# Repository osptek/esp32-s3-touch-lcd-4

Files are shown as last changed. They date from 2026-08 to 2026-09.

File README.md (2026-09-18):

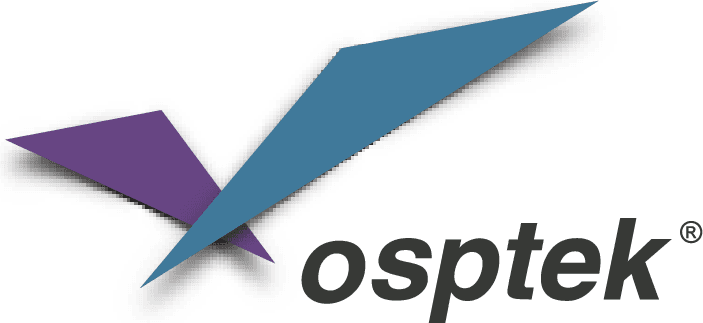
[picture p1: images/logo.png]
OSPTEK


<h1 align="center">OSPTEK ESP32-S3-Touch-LCD-4 系列</h1>

<p align="center"><b>4 寸触摸面板 · 多版本索引 · ESP32-S3</b></p>

<p align="center"><a href="./README_EN.md">English</a> | 简体中文</p>

<p align="center">
  
  
  
  
</p>

## 目录

- [说明](#说明)
- [版本一览](#版本一览)
- [ESP32-S3-Touch-LCD-4](#esp32-s3-touch-lcd-4)
- [ESP32-S3-Touch-4-Classic](#esp32-s3-touch-4-classic)
- [ESP32-S3-Touch-4-Pro](#esp32-s3-touch-4-pro)
- [ESP32-S3-Touch-4-220V](#esp32-s3-touch-4-220v)
- [外壳 CAD](#外壳-cad)
- [购买链接](#购买链接)
- [技术支持](#技术支持)

---

## 说明

本仓库收录 **ESP32-S3-Touch-LCD-4 系列** 4 寸触摸屏面板成品资料。

**根目录 README 为导航页**。下表可快速浏览各版本；点击「完整资料」进入 `versions/` 下对应**型号文件夹**（产品页、规格书、示例、固件均在该目录内）。

仓库名：`esp32-s3-touch-lcd-4`

---

## 版本一览

| 版本 | 宣传图 | 简介 | 完整资料 |
| ---- | --- | ---- | --- |
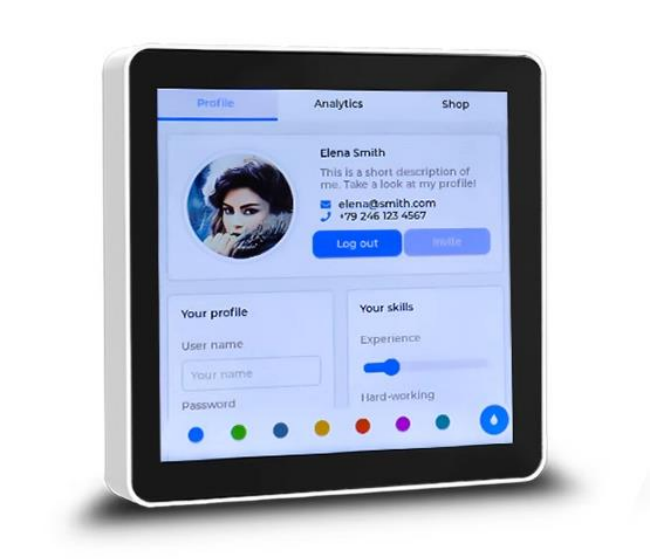
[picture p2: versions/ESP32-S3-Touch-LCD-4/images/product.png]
ESP32-S3-Touch-LCD-4
| ESP32-S3-Touch-LCD-4 |  | [简介](#esp32-s3-touch-lcd-4) | [完整资料](./versions/ESP32-S3-Touch-LCD-4/) |
| ESP32-S3-Touch-4-Classic | ESP32-S3-Touch-4-Classic | [简介](#esp32-s3-touch-4-classic) | [完整资料](./versions/ESP32-S3-Touch-4-Classic/) |
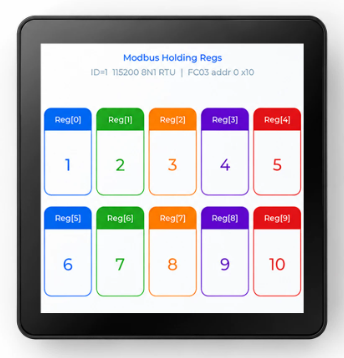
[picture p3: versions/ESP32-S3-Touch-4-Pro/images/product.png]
ESP32-S3-Touch-4-Pro
| ESP32-S3-Touch-4-Pro |  | [简介](#esp32-s3-touch-4-pro) | [完整资料](./versions/ESP32-S3-Touch-4-Pro/) |
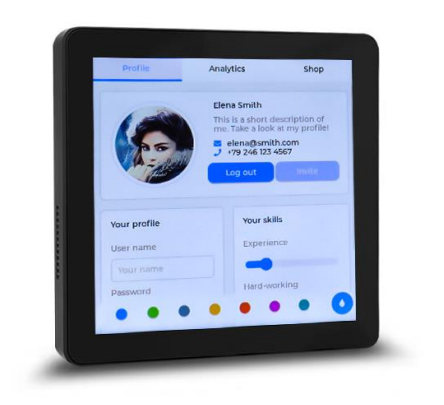
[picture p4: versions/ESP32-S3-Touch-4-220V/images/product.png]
ESP32-S3-Touch-4-220V
| ESP32-S3-Touch-4-220V |  | [简介](#esp32-s3-touch-4-220v) | [完整资料](./versions/ESP32-S3-Touch-4-220V/) |

---

## ESP32-S3-Touch-LCD-4

<p align="center">ESP32-S3-Touch-LCD-4</p>

**说明：** 旧版硬件（ESP32-TPCB4）；USB 5V / 12–24 VDC；一路 RS485。

完整产品页、规格书与示例：[versions/ESP32-S3-Touch-LCD-4/](./versions/ESP32-S3-Touch-LCD-4/)

---

## ESP32-S3-Touch-4-Classic

<p align="center">ESP32-S3-Touch-4-Classic</p>

**说明：** 新版基础板（原理图 `ESP32-S3-Touch基础板V1.0`）；示例工程 / 预编译固件已在本版验证。

完整产品页、规格书与示例：[versions/ESP32-S3-Touch-4-Classic/](./versions/ESP32-S3-Touch-4-Classic/)

---

## ESP32-S3-Touch-4-Pro

<p align="center">ESP32-S3-Touch-4-Pro</p>

**说明：** 新版 Pro；在 Classic 基础上增加板载音频（ES8311 + NS4150B）。

完整产品页、规格书与示例：[versions/ESP32-S3-Touch-4-Pro/](./versions/ESP32-S3-Touch-4-Pro/)

---

## ESP32-S3-Touch-4-220V

<p align="center">ESP32-S3-Touch-4-220V</p>

**说明：** 220V 交流供电版（AC 85–265 V）；一路 RS485。

完整产品页、规格书与示例：[versions/ESP32-S3-Touch-4-220V/](./versions/ESP32-S3-Touch-4-220V/)

---

## 外壳 CAD

本系列 **86 型外壳**（2 层 / 4 层）全型号通用。

**4 层外壳**

- [`0302(1).dwg`](./docs/86-enclosure-4-layer/0302(1).dwg)
- [`WSD4寸-2d-1116.dwg`](./docs/86-enclosure-4-layer/WSD4%E5%AF%B8-2d-1116.dwg)

**2 层外壳**

- [`3.95-01 PCB.dwg`](./docs/86-enclosure-2-layer/3.95-01%20PCB.dwg)
- [`增加开口结构外壳20250102.dwg`](./docs/86-enclosure-2-layer/%E5%A2%9E%E5%8A%A0%E5%BC%80%E5%8F%A3%E7%BB%93%E6%9E%84%E5%A4%96%E5%A3%B320250102.dwg)
- [`装配0718(1).DWG`](./docs/86-enclosure-2-layer/%E8%A3%85%E9%85%8D0718(1).DWG)

---

## 购买链接

<p align="center">
  
  &nbsp;&nbsp;
  
</p>

**国内（淘宝）**

- 店铺：[鱼鹰光电工厂店](https://shop110742373.taobao.com/)

**海外（AliExpress）**

- 店铺：[OSPTEK Official Store](https://www.aliexpress.com/store/1105701619)

---

## 技术支持

- 技术支持 / 产品咨询：<luyu@osptek.com>
- QQ 技术交流群：**985881096**
- 公司官网：<https://osptek.com/>
- 有任何问题，都可以在本仓库 Issues 中提问

---

<p align="center"><sub>© 2026 OSPTEK 鱼鹰光电 · 本仓库资料采用 CC BY 4.0 许可</sub></p>

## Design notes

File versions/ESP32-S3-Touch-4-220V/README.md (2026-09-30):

<p align="left">OSPTEK</p>

<h1 align="center">OSPTEK ESP32-S3-Touch-4-220V 触摸屏面板</h1>

<p align="center"><b>4 寸触摸 · 220V 供电 · RS485 · Wi-Fi / BLE</b></p>

<p align="center"><a href="./README_EN.md">English</a> | 简体中文 · <a href="../../README.md">系列索引</a></p>

<p align="center">
  
  
  
  
</p>

<p align="center">OSPTEK ESP32-S3-Touch-4-220V 产品图</p>

## 目录

- [产品简介](#产品简介)
- [产品特性](#产品特性)
- [应用场景](#应用场景)
- [规格参数](#规格参数)
- [屏幕](#屏幕)
- [硬件资源](#硬件资源)
- [开发说明](#开发说明)
- [示例工程](#示例工程)
- [预编译固件](#预编译固件)
- [仓库结构](#仓库结构)
- [相关资料](#相关资料)
- [购买链接](#购买链接)
- [技术支持](#技术支持)

---

## 产品简介

> 📌 本版本对应 **ESP32-S3-Touch-4-220V**。参数以仓库 `docs/` 内使用指南为准。

OSPTEK **ESP32-S3-Touch-4-220V** 是一款集成 **4 英寸 RGB 触摸显示**、**ESP32-S3**（Wi-Fi / BLE）主控、**220V 交流输入电源模块**以及 **RS485** 通信接口的智能触摸控制平台，适用于智能家居控制、工业控制面板、设备联网与人机交互等场景。

## 产品特性

- **4 寸方屏触摸**：YDP395BT009-V1，480×480，ST7701S + 电容触摸
- **ESP32-S3 主控**：ESP32-S3-WROOM-1-N16R8，**16 MB Flash + 8 MB PSRAM**，Wi-Fi 与 BLE 5.0
- **220V 供电**：AC **85~265 V** 输入，DC **24 V** 输出
- **RS485**：工业现场通信接口
- **USB Type-C**：程序下载、调试及供电
- **喇叭**：声音提示 / 播放

## 应用场景

- 智能家居控制终端
- 工业设备控制面板
- 智能电力控制系统
- IoT 物联网网关
- 自动化设备人机界面

## 规格参数

### 主控与存储

| 项目 | 规格 |
| ---- | ---- |
| 产品型号 | ESP32-S3-Touch-4-220V |
| 主控模组 | ESP32-S3-WROOM-1-N16R8 |
| Flash | 16 MB |
| PSRAM | 8 MB |
| 无线 | Wi-Fi、Bluetooth LE 5.0 |

### 显示与触摸

| 项目 | 规格 |
| ---- | ---- |
| 屏模组 | YDP395BT009-V1（约 3.95 英寸） |
| 分辨率 | 480×480 |
| 驱动 IC | ST7701S |
| 显示接口 | RGB 18-bit |
| 触摸 | 电容触摸（FT6336U，I²C） |
| 亮度 | 典型 350 cd/m² |

完整模组参数见下方 [屏幕](#屏幕)。

### 电源与接口

| 项目 | 规格 |
| ---- | ---- |
| 交流输入 | AC 85~265 V（端子：220V 电源输入） |
| 直流输出 | 24 V DC（端子：DO / 24V 输出；电源模块典型 24 V / 410 mA） |
| RS485 | RS485A / RS485B |
| USB | Type-C（下载、调试、供电） |
| 音频 | 板载喇叭 |

> ⚠ 220V 交流输入属高压区域，禁止带电操作；首次使用前请确认接线正确。建议由具备电气操作经验的人员安装调试。详见[使用指南](./docs/ESP32-S3-TOUCH-4-220V_%E4%BD%BF%E7%94%A8%E6%8C%87%E5%8D%97260731.pdf)。

## 屏幕

本面板搭载 OSPTEK 自产 TFT 模组 **YDP395BT009-V1**，驱动 IC 为 **ST7701S**，通过主板 LCD FPC 连接；触摸为电容方案（I²C，FT6336U）。

### 模组规格（YDP395BT009-V1）

| 项目 | 规格 |
| ---- | ---- |
| 模组型号 | YDP395BT009-V1 |
| 尺寸 | 3.95 英寸（对角线） |
| 显示模式 | Normally Black |
| 分辨率 | 480（H）RGB × 480（V） |
| 点距 | 153 μm × 153 μm |
| 有效显示区 | 71.86 × 70.18 mm |
| 模组外形 | 83.85 × 83.85 × 3.27 mm |
| 排列 | RGB 垂直条纹 |
| 接口 | RGB 18-bit（含 HSYNC / VSYNC / DE / DCLK）；驱动初始化为 3-wire SPI（SDA / SCL / CS） |
| 驱动 IC | ST7701S |
| 亮度 | 典型 350 cd/m²（最小约 300） |
| 视角 | 全视角（典型约 80°） |
| 对比度 | 典型约 1000:1 |
| 背光 | 8 颗白光 LED（背光供电典型约 12 V / 40 mA） |
| 工作温度 | −20 ℃ ~ +70 ℃ |
| 存储温度 | −30 ℃ ~ +80 ℃ |

触摸侧经同一 FPC 引出 `TP_SCL` / `TP_SDA` / `TP_INT` / `TP_RESET` 等信号，供电典型 2.8–3.3 V。

### 屏幕相关资料

- [屏模组规格书 YDP395BT009-V1（PDF）](./docs/YDP395BT009-V1.pdf)
- [总成图 CAD（YDP395BT009-V1）](./docs/YDP395BT009-V1.dwg)
- [驱动 IC ST7701S Datasheet（PDF）](./docs/ST7701S_SPEC_V1.3.pdf)
- [触摸 IC FT6336U Datasheet（PDF）](./docs/FT6336U_DataSheet_V1.1.pdf)
- [初始化序列（文本）](./docs/BOE3.95_480x480_ST7701S_init.txt)

## 硬件资源

### 外观与电源板

<p align="center">
  ESP32-S3-Touch-4-220V 正面
  &nbsp;&nbsp;
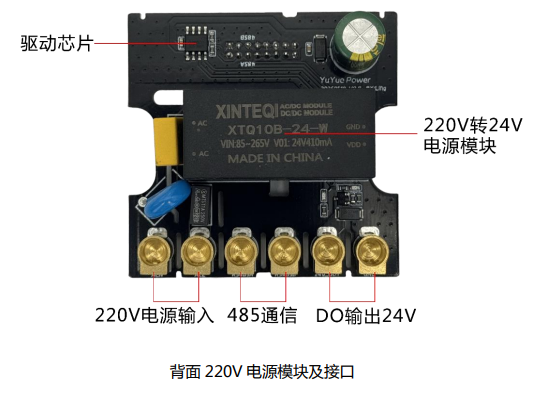
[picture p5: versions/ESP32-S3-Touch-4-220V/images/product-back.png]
背面 220V 电源模块及接口
  
</p>

### 主板标注

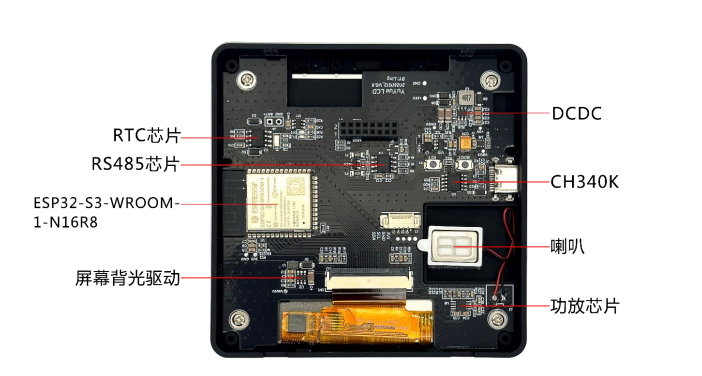
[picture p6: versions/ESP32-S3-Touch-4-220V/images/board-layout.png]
YuYue LCD 主板接口与器件标注


板载可见资源（标注图）：ESP32-S3-WROOM-1-N16R8、RS485、CH340K、DCDC、屏幕背光驱动、RTC、功放与喇叭、USB Type-C 等。

### 原理图预览

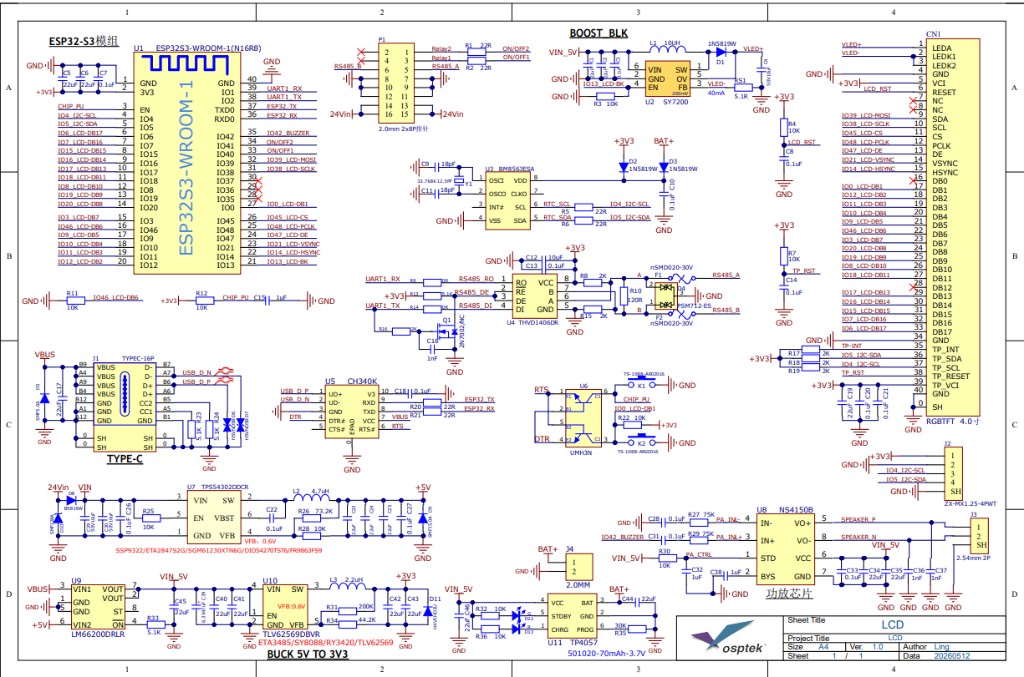
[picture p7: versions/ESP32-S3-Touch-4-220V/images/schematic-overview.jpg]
原理图预览


完整原理图 PDF：

- [YuYue LCD V1.0 原理图（PDF）](./docs/YuYue%20LCD_V1.0.pdf)
- [YuYue Power V0.8 原理图（PDF）](./docs/YuYue%20Power%20V0.8.pdf)

完整说明与接线见使用指南 PDF。

## 开发说明

1. 使用 **USB Type-C** 连接电脑进行程序下载与调试。
2. **验证显示（推荐）**：直接烧录仓库内预编译固件，见下方 [预编译固件](#预编译固件)。
3. **二次开发**：使用 ESP-IDF 编译 [示例工程](#示例工程)（与 Classic 同源）。

⚠ 220V 交流输入属高压区域，禁止带电操作；首次使用前请确认接线正确。

详细步骤与安全注意事项见：

- [使用指南（中文 PDF）](./docs/ESP32-S3-TOUCH-4-220V_%E4%BD%BF%E7%94%A8%E6%8C%87%E5%8D%97260731.pdf)
- [User Guide (English PDF)](./docs/ESP32-S3-Touch-4-220V_User%20Guide260731.pdf)

乐鑫官方工具与入门：

- [Flash 下载工具（Windows）](https://www.espressif.com/zh-hans/support/download/other-tools)
- [ESP-IDF 快速入门 · ESP32-S3（中文）](https://docs.espressif.com/projects/esp-idf/zh_CN/latest/esp32s3/get-started/)
- [ESP-IDF Get Started · ESP32-S3（English）](https://docs.espressif.com/projects/esp-idf/en/latest/esp32s3/get-started/)

## 示例工程

触摸走乐鑫 `i2c_master` + `esp_lcd_touch_ft5x06`，已去掉旧版 `driver/i2c.h` / `i2c_driver_install`。屏为 RGB ST7701，480×480。

| 说明 | 路径 |
| ---- | ---- |
| ESP-IDF 5 · LVGL 8 通用 Demo | [`examples/s3-idf5_st7701-rgb_lvgl8-common-demo/`](./examples/s3-idf5_st7701-rgb_lvgl8-common-demo/) |
| ESP-IDF 5 · LVGL 9 通用 Demo | [`examples/s3-idf5_st7701-rgb_lvgl9-common-demo/`](./examples/s3-idf5_st7701-rgb_lvgl9-common-demo/) |
| ESP-IDF 5 · 3.95 寸盒体工程（rev2） | [`examples/ESP32S3_3.95In_Box_rev2/`](./examples/ESP32S3_3.95In_Box_rev2/) |
| ESP-IDF 5 · LVGL 8 游戏 Demo | [`examples/esp32s3_st7701_lvgl-game/`](./examples/esp32s3_st7701_lvgl-game/) |
| ESP-IDF 5 · LVGL 9 Lottie 播放 | [`examples/esp32s3-idf5_st7701-rgb_lvgl9-lottie-player/`](./examples/esp32s3-idf5_st7701-rgb_lvgl9-lottie-player/) |
| ESP-IDF 6 · LVGL 8 通用 Demo | [`examples/esp32s3-idf6_st7701-rgb_lvgl8-common-demo/`](./examples/esp32s3-idf6_st7701-rgb_lvgl8-common-demo/) |
| ESP-IDF 6 · LVGL 9 通用 Demo | [`examples/esp32s3-idf6_st7701-rgb_lvgl9-common-demo/`](./examples/esp32s3-idf6_st7701-rgb_lvgl9-common-demo/) |

> 下列示例与 Classic 同源（同一屏模组与触摸方案）。

在已安装对应版本 ESP-IDF 的环境下（IDF 5 工程建议 ≥5.5；IDF 6 工程用 IDF 6）：

```bash
cd examples/s3-idf5_st7701-rgb_lvgl8-common-demo
idf.py set-target esp32s3
idf.py build
idf.py -p <串口> flash monitor
```

组件依赖由各工程 `main/idf_component.yml` 管理，首次编译会自动拉取。

## 预编译固件

| 文件 | 烧录地址 | 说明 |
| ---- | --- | ---- |
| [`firmware/esp32-s3-touch-lcd-4.bin`](./firmware/esp32-s3-touch-lcd-4.bin) | **`0x0`** | 合并烧录镜像（bootloader + 分区表 + 应用），出厂演示固件 |

Flash 参数与工程配置一致：芯片 **ESP32-S3**，Flash **16 MB**，**DIO**，**80 MHz**。合并包从地址 **`0x0`** 整包写入。

### 方式一：Flash 下载工具（Windows，推荐上手）

1. 下载并打开乐鑫 **[Flash 下载工具](https://www.espressif.com/zh-hans/support/download/other-tools)**。
2. `ChipType` 选 **ESP32-S3**，`WorkMode` 选 Develop，`LoadMode` 选 UART。
3. 勾选一行，固件选 [`firmware/esp32-s3-touch-lcd-4.bin`](./firmware/esp32-s3-touch-lcd-4.bin)，地址填 **`0x0`**。
4. SPI SPEED / SPI MODE / FLASH SIZE 按上表选择（80 MHz、DIO、16 MB）。
5. 选择正确 COM 口，点 **START** 烧录。

### 方式二：esptool（命令行）

```bash
esptool.py --chip esp32s3 -p <串口> write_flash 0x0 firmware/esp32-s3-touch-lcd-4.bin
```

## 仓库结构

```text
esp32-s3-touch-lcd-4/                                # 仓库根（导航见 ../../README.md）
└── versions/
    └── ESP32-S3-Touch-4-220V/                       # 本型号完整资料
        ├── README.md
        ├── README_EN.md
        ├── images/
        ├── docs/
        ├── firmware/
        └── examples/
```

## 相关资料

- [使用指南（中文 PDF）](./docs/ESP32-S3-TOUCH-4-220V_%E4%BD%BF%E7%94%A8%E6%8C%87%E5%8D%97260731.pdf)
- [User Guide (English PDF)](./docs/ESP32-S3-Touch-4-220V_User%20Guide260731.pdf)
- [YuYue LCD V1.0 原理图（PDF）](./docs/YuYue%20LCD_V1.0.pdf)
- [YuYue Power V0.8 原理图（PDF）](./docs/YuYue%20Power%20V0.8.pdf)
- [屏模组规格书 YDP395BT009-V1（PDF）](./docs/YDP395BT009-V1.pdf)
- [总成图 CAD（YDP395BT009-V1）](./docs/YDP395BT009-V1.dwg)
- [驱动 IC ST7701S Datasheet（PDF）](./docs/ST7701S_SPEC_V1.3.pdf)
- [触摸 IC FT6336U Datasheet（PDF）](./docs/FT6336U_DataSheet_V1.1.pdf)
- [初始化序列（文本）](./docs/BOE3.95_480x480_ST7701S_init.txt)

### 系列通用外壳 CAD

86 型外壳（2 层 / 4 层）全型号通用，文件在仓库根 `docs/`。

- [4 层：`0302(1).dwg`](../../docs/86-enclosure-4-layer/0302(1).dwg)
- [4 层：`WSD4寸-2d-1116.dwg`](../../docs/86-enclosure-4-layer/WSD4%E5%AF%B8-2d-1116.dwg)
- [2 层：`3.95-01 PCB.dwg`](../../docs/86-enclosure-2-layer/3.95-01%20PCB.dwg)
- [2 层：`增加开口结构外壳20250102.dwg`](../../docs/86-enclosure-2-layer/%E5%A2%9E%E5%8A%A0%E5%BC%80%E5%8F%A3%E7%BB%93%E6%9E%84%E5%A4%96%E5%A3%B320250102.dwg)
- [2 层：`装配0718(1).DWG`](../../docs/86-enclosure-2-layer/%E8%A3%85%E9%85%8D0718(1).DWG)

### 芯片资料（乐鑫官方）

- [ESP32-S3 系列产品页（中文）](https://www.espressif.com/zh-hans/products/socs/esp32-s3)
- [ESP-IDF 编程指南 · ESP32-S3（中文）](https://docs.espressif.com/projects/esp-idf/zh_CN/latest/esp32s3/index.html)

## 购买链接

<p align="center">
  
  &nbsp;&nbsp;
  
</p>

**国内（淘宝）**

- 店铺：[鱼鹰光电工厂店](https://shop110742373.taobao.com/)

**海外（AliExpress）**

- 店铺：[OSPTEK Official Store](https://www.aliexpress.com/store/1105701619)

---

## 技术支持

- 技术支持 / 产品咨询：<luyu@osptek.com>
- QQ 技术交流群：**985881096**
- 公司官网：<https://osptek.com/>
- 有任何问题，都可以在本仓库 Issues 中提问

---

<p align="center"><sub>© 2026 OSPTEK 鱼鹰光电 · 本仓库资料采用 CC BY 4.0 许可</sub></p>

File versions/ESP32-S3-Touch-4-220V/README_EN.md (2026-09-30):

<p align="left">OSPTEK</p>

<h1 align="center">OSPTEK ESP32-S3-Touch-4-220V Touch Panel</h1>

<p align="center"><b>4" Touch · 220V Power · RS485 · Wi-Fi / BLE</b></p>

<p align="center">English | <a href="./README.md">简体中文</a> · <a href="../../README_EN.md">Family index</a></p>

<p align="center">
  
  
  
  
</p>

<p align="center">OSPTEK ESP32-S3-Touch-4-220V product image</p>

## Contents

- [Overview](#overview)
- [Other SKUs in this series](#other-skus-in-this-series)
- [Features](#features)
- [Applications](#applications)
- [Specifications](#specifications)
- [Display](#display)
- [Hardware Resources](#hardware-resources)
- [Development Notes](#development-notes)
- [Examples](#examples)
- [Prebuilt Firmware](#prebuilt-firmware)
- [Repository Structure](#repository-structure)
- [Documentation](#documentation)
- [Where to Buy](#where-to-buy)
- [Support](#support)

---

## Overview

> 📌 This SKU is **ESP32-S3-Touch-4-220V**. Specs follow the user guides in `docs/`.

OSPTEK **ESP32-S3-Touch-4-220V** integrates a **4-inch RGB capacitive touch display**, an **ESP32-S3** (Wi-Fi / BLE) module, a **220V AC input power stage**, and an **RS485** interface—suited for smart-home control, industrial panels, networked devices, and HMI terminals.

## Features

- **4" square touch panel**: YDP395BT009-V1, 480×480, ST7701S + capacitive touch
- **ESP32-S3**: ESP32-S3-WROOM-1-N16R8, **16 MB Flash + 8 MB PSRAM**, Wi-Fi and BLE 5.0
- **220V power**: AC **85~265 V** in, DC **24 V** out
- **RS485** industrial communication
- **USB Type-C** for flash, debug, and power
- **Speaker** for audio alerts

## Applications

- Smart-home control terminals
- Industrial equipment control panels
- Smart power systems
- IoT gateways
- Automation HMI

## Specifications

### MCU & Memory

| Item | Specification |
| ---- | --- |
| Product | ESP32-S3-Touch-4-220V |
| Module | ESP32-S3-WROOM-1-N16R8 |
| Flash | 16 MB |
| PSRAM | 8 MB |
| Wireless | Wi-Fi, Bluetooth LE 5.0 |

### Display & Touch

| Item | Specification |
| ---- | --- |
| Panel module | YDP395BT009-V1 (~3.95") |
| Resolution | 480×480 |
| Driver IC | ST7701S |
| Display interface | RGB 18-bit |
| Touch | Capacitive (FT6336U, I²C) |
| Brightness | 350 cd/m² typ. |

Full module details are in [Display](#display) below.

### Power & Interfaces

| Item | Specification |
| ---- | --- |
| AC input | AC 85~265 V (terminal: 220V power in) |
| DC output | 24 V DC (terminal: DO / 24V out; module typ. 24 V / 410 mA) |
| RS485 | RS485A / RS485B |
| USB | Type-C (flash, debug, power) |
| Audio | Onboard speaker |

> ⚠ Mains AC is hazardous—do not work live. Confirm wiring before first power-up. Installation by qualified personnel is recommended. See the [User Guide](./docs/ESP32-S3-Touch-4-220V_User%20Guide260731.pdf).

## Display

This panel uses OSPTEK TFT module **YDP395BT009-V1**, driver IC **ST7701S**, connected via the LCD FPC; touch is capacitive (I²C, FT6336U).

### Module Specs (YDP395BT009-V1)

| Item | Specification |
| ---- | --- |
| Module | YDP395BT009-V1 |
| Size | 3.95" diagonal |
| Display mode | Normally Black |
| Resolution | 480 (H) RGB × 480 (V) |
| Pixel pitch | 153 μm × 153 μm |
| Active area | 71.86 × 70.18 mm |
| Module outline | 83.85 × 83.85 × 3.27 mm |
| Arrangement | RGB vertical stripe |
| Interface | RGB 18-bit (HSYNC / VSYNC / DE / DCLK); init via 3-wire SPI (SDA / SCL / CS) |
| Driver IC | ST7701S |
| Brightness | 350 cd/m² typ. (min. ~300) |
| Viewing angle | All view (~80° typ.) |
| Contrast | ~1000:1 typ. |
| Backlight | 8 white LEDs (~12 V / 40 mA typ.) |
| Operating temp. | −20 ℃ ~ +70 ℃ |
| Storage temp. | −30 ℃ ~ +80 ℃ |

Touch signals `TP_SCL` / `TP_SDA` / `TP_INT` / `TP_RESET` share the same FPC; supply typically 2.8–3.3 V.

### Display Documents

- [Panel datasheet YDP395BT009-V1 (PDF)](./docs/YDP395BT009-V1.pdf)
- [Assembly CAD (YDP395BT009-V1)](./docs/YDP395BT009-V1.dwg)
- [Driver IC ST7701S datasheet (PDF)](./docs/ST7701S_SPEC_V1.3.pdf)
- [Touch IC FT6336U datasheet (PDF)](./docs/FT6336U_DataSheet_V1.1.pdf)
- [Init sequence (text)](./docs/BOE3.95_480x480_ST7701S_init.txt)

## Hardware Resources

### Product & Power Board

<p align="center">
  ESP32-S3-Touch-4-220V front
  &nbsp;&nbsp;
  Rear 220V power module and terminals
</p>

### Board Layout

<p align="center">YuYue LCD board layout</p>

Labeled resources include ESP32-S3-WROOM-1-N16R8, RS485, CH340K, DCDC, backlight driver, RTC, audio amp / speaker, USB Type-C, and more.

### Schematic Overview

<p align="center">Schematic overview</p>

Full schematic PDFs:

- [YuYue LCD V1.0 schematic (PDF)](./docs/YuYue%20LCD_V1.0.pdf)
- [YuYue Power V0.8 schematic (PDF)](./docs/YuYue%20Power%20V0.8.pdf)

Full wiring and safety notes are in the PDF guides.

## Development Notes

1. Use **USB Type-C** to flash and debug.
2. **Verify the display (recommended)**: flash the prebuilt firmware—see [Prebuilt Firmware](#prebuilt-firmware).
3. **Application development**: build the [example](#examples) with ESP-IDF (same sources as Classic).

⚠ AC 220V input is hazardous; do not work on live wiring. Confirm wiring before first power-up.

Guides:

- [使用指南（中文 PDF）](./docs/ESP32-S3-TOUCH-4-220V_%E4%BD%BF%E7%94%A8%E6%8C%87%E5%8D%97260731.pdf)
- [User Guide (English PDF)](./docs/ESP32-S3-Touch-4-220V_User%20Guide260731.pdf)

Espressif:

- [Flash Download Tools (Windows)](https://www.espressif.com/en/support/download/other-tools)
- [ESP-IDF Get Started · ESP32-S3](https://docs.espressif.com/projects/esp-idf/en/latest/esp32s3/get-started/)

## Examples

Touch uses Espressif `i2c_master` + `esp_lcd_touch_ft5x06` (legacy `driver/i2c.h` / `i2c_driver_install` removed). Panel: RGB ST7701, 480×480.

| Description | Path |
| --- | ---- |
| ESP-IDF 5 · LVGL 8 common demo | [`examples/s3-idf5_st7701-rgb_lvgl8-common-demo/`](./examples/s3-idf5_st7701-rgb_lvgl8-common-demo/) |
| ESP-IDF 5 · LVGL 9 common demo | [`examples/s3-idf5_st7701-rgb_lvgl9-common-demo/`](./examples/s3-idf5_st7701-rgb_lvgl9-common-demo/) |
| ESP-IDF 5 · 3.95" box project (rev2) | [`examples/ESP32S3_3.95In_Box_rev2/`](./examples/ESP32S3_3.95In_Box_rev2/) |
| ESP-IDF 5 · LVGL 8 game demo | [`examples/esp32s3_st7701_lvgl-game/`](./examples/esp32s3_st7701_lvgl-game/) |
| ESP-IDF 5 · LVGL 9 Lottie player | [`examples/esp32s3-idf5_st7701-rgb_lvgl9-lottie-player/`](./examples/esp32s3-idf5_st7701-rgb_lvgl9-lottie-player/) |
| ESP-IDF 6 · LVGL 8 common demo | [`examples/esp32s3-idf6_st7701-rgb_lvgl8-common-demo/`](./examples/esp32s3-idf6_st7701-rgb_lvgl8-common-demo/) |
| ESP-IDF 6 · LVGL 9 common demo | [`examples/esp32s3-idf6_st7701-rgb_lvgl9-common-demo/`](./examples/esp32s3-idf6_st7701-rgb_lvgl9-common-demo/) |

> Same example sources as the Classic SKU (same panel and touch).

With the matching ESP-IDF installed (IDF 5 projects: ≥5.5; IDF 6 projects: IDF 6):

```bash
cd examples/s3-idf5_st7701-rgb_lvgl8-common-demo
idf.py set-target esp32s3
idf.py build
idf.py -p <PORT> flash monitor
```

Dependencies are managed by each project's `main/idf_component.yml` and fetched on first build.

## Prebuilt Firmware

| File | Address | Notes |
| ---- | --- | ---- |
| [`firmware/esp32-s3-touch-lcd-4.bin`](./firmware/esp32-s3-touch-lcd-4.bin) | **`0x0`** | Merged image (bootloader + partition table + app), factory demo firmware |

Flash settings: chip **ESP32-S3**, Flash **16 MB**, **DIO**, **80 MHz**. Write the merged image from **`0x0`**.

### Option A: Flash Download Tools (Windows)

1. Open Espressif **[Flash Download Tools](https://www.espressif.com/en/support/download/other-tools)**.
2. `ChipType` **ESP32-S3**, `WorkMode` Develop, `LoadMode` UART.
3. Select [`firmware/esp32-s3-touch-lcd-4.bin`](./firmware/esp32-s3-touch-lcd-4.bin), address **`0x0`**.
4. SPI SPEED / MODE / FLASH SIZE: 80 MHz, DIO, 16 MB.
5. Choose the COM port and click **START**.

### Option B: esptool

```bash
esptool.py --chip esp32s3 -p <PORT> write_flash 0x0 firmware/esp32-s3-touch-lcd-4.bin
```

## Repository layout

```text
esp32-s3-touch-lcd-4/                                # repo root (nav: ../../README_EN.md)
└── versions/
    └── ESP32-S3-Touch-4-220V/                       # full materials for this SKU
        ├── README.md
        ├── README_EN.md
        ├── images/
        ├── docs/
        ├── firmware/
        └── examples/
```

## Documentation

- [使用指南（中文 PDF）](./docs/ESP32-S3-TOUCH-4-220V_%E4%BD%BF%E7%94%A8%E6%8C%87%E5%8D%97260731.pdf)
- [User Guide (English PDF)](./docs/ESP32-S3-Touch-4-220V_User%20Guide260731.pdf)
- [YuYue LCD V1.0 schematic (PDF)](./docs/YuYue%20LCD_V1.0.pdf)
- [YuYue Power V0.8 schematic (PDF)](./docs/YuYue%20Power%20V0.8.pdf)
- [Panel datasheet YDP395BT009-V1 (PDF)](./docs/YDP395BT009-V1.pdf)
- [Assembly CAD (YDP395BT009-V1)](./docs/YDP395BT009-V1.dwg)
- [Driver IC ST7701S datasheet (PDF)](./docs/ST7701S_SPEC_V1.3.pdf)
- [Touch IC FT6336U datasheet (PDF)](./docs/FT6336U_DataSheet_V1.1.pdf)
- [Init sequence (text)](./docs/BOE3.95_480x480_ST7701S_init.txt)

### Shared enclosure CAD

The 86-type enclosure (2-layer / 4-layer) is shared by every SKU. Files live in the repo-root `docs/` folder.

- [4-layer: `0302(1).dwg`](../../docs/86-enclosure-4-layer/0302(1).dwg)
- [4-layer: `WSD4寸-2d-1116.dwg`](../../docs/86-enclosure-4-layer/WSD4%E5%AF%B8-2d-1116.dwg)
- [2-layer: `3.95-01 PCB.dwg`](../../docs/86-enclosure-2-layer/3.95-01%20PCB.dwg)
- [2-layer: `增加开口结构外壳20250102.dwg`](../../docs/86-enclosure-2-layer/%E5%A2%9E%E5%8A%A0%E5%BC%80%E5%8F%A3%E7%BB%93%E6%9E%84%E5%A4%96%E5%A3%B320250102.dwg)
- [2-layer: `装配0718(1).DWG`](../../docs/86-enclosure-2-layer/%E8%A3%85%E9%85%8D0718(1).DWG)

### Espressif

- [ESP32-S3 product page](https://www.espressif.com/en/products/socs/esp32-s3)
- [ESP-IDF Programming Guide · ESP32-S3](https://docs.espressif.com/projects/esp-idf/en/latest/esp32s3/index.html)

## Where to Buy

<p align="center">
  
  &nbsp;&nbsp;
  
</p>

**International (AliExpress)**

- Store: [OSPTEK Official Store](https://www.aliexpress.com/store/1105701619)

**China (Taobao)**

- Store: [鱼鹰光电工厂店](https://shop110742373.taobao.com/)

---

## Support

- Technical support / product inquiry: <luyu@osptek.com>
- QQ technical group: **985881096**
- Website: <https://osptek.com/>
- Feel free to open an Issue in this repository if you have any questions

---

<p align="center"><sub>© 2026 OSPTEK · Materials in this repository are licensed under CC BY 4.0</sub></p>

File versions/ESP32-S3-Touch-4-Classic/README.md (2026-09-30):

<p align="left">OSPTEK</p>

<h1 align="center">OSPTEK ESP32-S3-Touch-4-Classic 触摸屏面板</h1>

<p align="center"><b>86 型面板 · 触摸交互 · 一路 RS485</b></p>

<p align="center"><a href="./README_EN.md">English</a> | 简体中文 · <a href="../../README.md">系列索引</a></p>

<p align="center">
  
  
  
  
</p>

<p align="center">OSPTEK ESP32-S3-Touch-4-Classic 产品宣传图</p>

## 目录

- [产品简介](#产品简介)
- [产品特性](#产品特性)
- [应用场景](#应用场景)
- [规格参数](#规格参数)
- [屏幕](#屏幕)
- [硬件资源](#硬件资源)
- [快速开始](#快速开始)
- [示例工程](#示例工程)
- [预编译固件](#预编译固件)
- [仓库结构](#仓库结构)
- [相关资料](#相关资料)
- [购买链接](#购买链接)
- [技术支持](#技术支持)

---

## 产品简介

> 📌 本文档对应 **ESP32-S3-Touch-4-Classic**（原理图：`ESP32-S3-Touch基础板V1.0`）。本目录内示例工程 / 预编译固件已在 Classic 板上验证。

OSPTEK **ESP32-S3-Touch-4-Classic** 是一款搭载 ESP32-S3（2.4 GHz Wi-Fi + Bluetooth LE 5）模组的 **4 英寸触摸屏面板**，集成 **16 MB Flash** 与 **8 MB PSRAM**，板载 **YDP395BT009-V1**（约 3.95"）**480×480** RGB 电容触摸屏（驱动 **ST7701S**）。

主控模组为 **ESP32-S3-WROOM-1-N16R8**，板载一路 **RS485**、USB Type-C（供电 / 烧录）、I²C 与蜂鸣器等，适合作为智能中控、交互面板等方案的整机形态产品。

## 产品特性

- **4 寸方屏触摸**：YDP395BT009-V1，480×480，ST7701S + 电容触摸，适合 86 型面板人机界面
- **ESP32-S3 主控**：Wi-Fi + BLE 5，16 MB Flash + 8 MB PSRAM
- **工业总线**：板载 RS485
- **供电**：USB Type-C；接线端口支持宽压输入（见原理图）
- **调试**：CH340K USB 转串口
- **扩展**：I²C、LCD FPC、蜂鸣器等（见原理图）

## 应用场景

- 智能家居中控 / 86 型交互面板
- 家庭网关与本地人机界面
- 工业控制与设备状态显示
- 智能灯控与楼宇面板

## 规格参数

### 主控与存储

| 项目 | 规格 |
| ---- | ---- |
| 产品型号 | ESP32-S3-Touch-4-Classic |
| 主板 / 原理图 | ESP32-S3-Touch 基础板 V1.0 |
| 主控模组 | ESP32-S3-WROOM-1-N16R8 |
| Flash | 16 MB |
| PSRAM | 8 MB |
| 无线 | 2.4 GHz Wi-Fi、Bluetooth LE 5 |

### 显示与触摸

概览如下；完整模组参数、驱动与触摸说明见 [屏幕](#屏幕)。

| 项目 | 规格 |
| ---- | ---- |
| 屏模组 | YDP395BT009-V1（约 3.95 英寸） |
| 分辨率 | 480×480 |
| 驱动 IC | ST7701S |
| 显示接口 | RGB 18-bit |
| 触摸 | 电容触摸（FT6336U，I²C） |
| 亮度 | 典型 350 cd/m² |

### 接口与电源

| 项目 | 规格 |
| ---- | ---- |
| USB | Type-C（供电、烧录） |
| USB 转串口 | CH340K |
| RS485 | 板载 |
| 传感器 | I²C |
| 听觉 | 板载蜂鸣器 |

电源树、收发器件与精确电气参数见 [原理图](./docs/ESP32-S3-Touch基础板V1.0.pdf)。

## 屏幕

本面板搭载 OSPTEK 自产 TFT 模组 **YDP395BT009-V1**，驱动 IC 为 **ST7701S**，通过主板 LCD FPC 连接；触摸为电容方案（I²C，FT6336U）。

### 模组规格（YDP395BT009-V1）

| 项目 | 规格 |
| ---- | ---- |
| 模组型号 | YDP395BT009-V1 |
| 尺寸 | 3.95 英寸（对角线） |
| 显示模式 | Normally Black |
| 分辨率 | 480（H）RGB × 480（V） |
| 点距 | 153 μm × 153 μm |
| 有效显示区 | 71.86 × 70.18 mm |
| 模组外形 | 83.85 × 83.85 × 3.27 mm |
| 排列 | RGB 垂直条纹 |
| 接口 | RGB 18-bit（含 HSYNC / VSYNC / DE / DCLK）；驱动初始化为 3-wire SPI（SDA / SCL / CS） |
| 驱动 IC | ST7701S |
| 亮度 | 典型 350 cd/m²（最小约 300） |
| 视角 | 全视角（典型约 80°） |
| 对比度 | 典型约 1000:1 |
| 背光 | 8 颗白光 LED（背光供电典型约 12 V / 40 mA） |
| 工作温度 | −20 ℃ ~ +70 ℃ |
| 存储温度 | −30 ℃ ~ +80 ℃ |

触摸侧经同一 FPC 引出 `TP_SCL` / `TP_SDA` / `TP_INT` / `TP_RESET` 等信号，供电典型 2.8–3.3 V。

### 屏幕相关资料

- [屏模组规格书 YDP395BT009-V1（PDF）](./docs/YDP395BT009-V1.pdf)
- [总成图 CAD（YDP395BT009-V1）](./docs/YDP395BT009-V1.dwg)
- [驱动 IC ST7701S Datasheet（PDF）](./docs/ST7701S_SPEC_V1.3.pdf)
- [触摸 IC FT6336U Datasheet（PDF）](./docs/FT6336U_DataSheet_V1.1.pdf)
- [初始化序列（文本）](./docs/BOE3.95_480x480_ST7701S_init.txt)

## 硬件资源

### 板载资源概览

| 资源 | 说明 |
| ---- | ---- |
| ESP32-S3-WROOM-1-N16R8 | Wi-Fi + BLE MCU 模组 |
| RS485 | 板载收发 |
| USB 转换 | CH340K |
| LCD 连接器 | FPC，连接 LCD |
| 蜂鸣器 | 板载 |

### 原理图

- [ESP32-S3-Touch 基础板 V1.0 原理图（PDF）](./docs/ESP32-S3-Touch基础板V1.0.pdf)

## 快速开始

1. 准备：ESP32-S3-Touch-4-Classic、可用的 USB 数据线（需支持数据传输，不仅充电）、电脑（Windows / Linux / macOS）。
2. 用 USB 连接电脑与面板的 USB 口。
3. **验证显示（推荐）**：直接烧录仓库内预编译固件，见下方 [预编译固件](#预编译固件)。
   - Windows 可用乐鑫官方图形工具 **[Flash 下载工具](https://www.espressif.com/zh-hans/support/download/other-tools)**（Flash Download Tools）烧录。
   - 使用说明见：[Flash 下载工具用户指南 · ESP32-S3](https://docs.espressif.com/projects/esp-test-tools/zh_CN/latest/esp32s3/production_stage/tools/flash_download_tool.html)
4. **二次开发**：使用 ESP-IDF 编译 [示例工程](#示例工程)（自动下载依赖串口 DTR/RTS，详见原理图）。

详细硬件说明见：

- [ESP32-S3-Touch 基础板 V1.0 原理图（PDF）](./docs/ESP32-S3-Touch基础板V1.0.pdf)

乐鑫官方工具与入门：

- [Flash 下载工具（Windows）](https://www.espressif.com/zh-hans/support/download/other-tools)
- [ESP-IDF 快速入门 · ESP32-S3（中文）](https://docs.espressif.com/projects/esp-idf/zh_CN/latest/esp32s3/get-started/)
- [ESP-IDF Get Started · ESP32-S3（English）](https://docs.espressif.com/projects/esp-idf/en/latest/esp32s3/get-started/)

## 示例工程

触摸走乐鑫 `i2c_master` + `esp_lcd_touch_ft5x06`，已去掉旧版 `driver/i2c.h` / `i2c_driver_install`。屏为 RGB ST7701，480×480。

| 说明 | 路径 |
| ---- | ---- |
| ESP-IDF 5 · LVGL 8 通用 Demo | [`examples/s3-idf5_st7701-rgb_lvgl8-common-demo/`](./examples/s3-idf5_st7701-rgb_lvgl8-common-demo/) |
| ESP-IDF 5 · LVGL 9 通用 Demo | [`examples/s3-idf5_st7701-rgb_lvgl9-common-demo/`](./examples/s3-idf5_st7701-rgb_lvgl9-common-demo/) |
| ESP-IDF 5 · 3.95 寸盒体工程（rev2） | [`examples/ESP32S3_3.95In_Box_rev2/`](./examples/ESP32S3_3.95In_Box_rev2/) |
| ESP-IDF 5 · LVGL 8 游戏 Demo | [`examples/esp32s3_st7701_lvgl-game/`](./examples/esp32s3_st7701_lvgl-game/) |
| ESP-IDF 5 · LVGL 9 Lottie 播放 | [`examples/esp32s3-idf5_st7701-rgb_lvgl9-lottie-player/`](./examples/esp32s3-idf5_st7701-rgb_lvgl9-lottie-player/) |
| ESP-IDF 6 · LVGL 8 通用 Demo | [`examples/esp32s3-idf6_st7701-rgb_lvgl8-common-demo/`](./examples/esp32s3-idf6_st7701-rgb_lvgl8-common-demo/) |
| ESP-IDF 6 · LVGL 9 通用 Demo | [`examples/esp32s3-idf6_st7701-rgb_lvgl9-common-demo/`](./examples/esp32s3-idf6_st7701-rgb_lvgl9-common-demo/) |

> 下列示例与预编译固件已在 **Classic** 板上验证。

在已安装对应版本 ESP-IDF 的环境下（IDF 5 工程建议 ≥5.5；IDF 6 工程用 IDF 6）：

```bash
cd examples/s3-idf5_st7701-rgb_lvgl8-common-demo
idf.py set-target esp32s3
idf.py build
idf.py -p <串口> flash monitor
```

组件依赖由各工程 `main/idf_component.yml` 管理，首次编译会自动拉取。

## 预编译固件

| 文件 | 烧录地址 | 说明 |
| ---- | --- | ---- |
| [`firmware/esp32-s3-touch-lcd-4.bin`](./firmware/esp32-s3-touch-lcd-4.bin) | **`0x0`** | 合并烧录镜像（bootloader + 分区表 + 应用），出厂演示固件 |

Flash 参数与工程配置一致：芯片 **ESP32-S3**，Flash **16 MB**，**DIO**，**80 MHz**。合并包从地址 **`0x0`** 整包写入。

### 方式一：Flash 下载工具（Windows，推荐上手）

1. 下载并打开乐鑫 **[Flash 下载工具](https://www.espressif.com/zh-hans/support/download/other-tools)**。
2. `ChipType` 选 **ESP32-S3**，`WorkMode` 选 Develop，`LoadMode` 选 UART。
3. 勾选一行，固件选 [`firmware/esp32-s3-touch-lcd-4.bin`](./firmware/esp32-s3-touch-lcd-4.bin)，地址填 **`0x0`**（不要填成应用分区的 `0x10000`）。
4. SPI SPEED / SPI MODE / FLASH SIZE 按上表选择（80 MHz、DIO、16 MB）。
5. 选择正确 COM 口，点 **START** 烧录。

详细界面说明见：[Flash 下载工具用户指南 · ESP32-S3](https://docs.espressif.com/projects/esp-test-tools/zh_CN/latest/esp32s3/production_stage/tools/flash_download_tool.html)

### 方式二：esptool（命令行）

将 `<串口>` 换成实际端口（如 `/dev/ttyUSB0`、`COM3`）；地址为 **`0x0`**：

```bash
esptool.py --chip esp32s3 -p <串口> write_flash 0x0 firmware/esp32-s3-touch-lcd-4.bin
```

## 仓库结构

```text
esp32-s3-touch-lcd-4/                                # 仓库根（导航见 ../../README.md）
└── versions/
    └── ESP32-S3-Touch-4-Classic/                    # 本型号完整资料
        ├── README.md
        ├── README_EN.md
        ├── images/
        ├── docs/
        ├── firmware/
        └── examples/
```

## 相关资料

### 本产品资料

- [ESP32-S3-Touch 基础板 V1.0 原理图（PDF）](./docs/ESP32-S3-Touch基础板V1.0.pdf)
- [屏模组规格书 YDP395BT009-V1（PDF）](./docs/YDP395BT009-V1.pdf)
- [总成图 CAD（YDP395BT009-V1）](./docs/YDP395BT009-V1.dwg)
- [驱动 IC ST7701S Datasheet（PDF）](./docs/ST7701S_SPEC_V1.3.pdf)
- [触摸 IC FT6336U Datasheet（PDF）](./docs/FT6336U_DataSheet_V1.1.pdf)
- [初始化序列（文本）](./docs/BOE3.95_480x480_ST7701S_init.txt)
- [示例工程](#示例工程)
- [预编译固件 esp32-s3-touch-lcd-4.bin](./firmware/esp32-s3-touch-lcd-4.bin)

### 系列通用外壳 CAD

86 型外壳（2 层 / 4 层）全型号通用，文件在仓库根 `docs/`。

- [4 层：`0302(1).dwg`](../../docs/86-enclosure-4-layer/0302(1).dwg)
- [4 层：`WSD4寸-2d-1116.dwg`](../../docs/86-enclosure-4-layer/WSD4%E5%AF%B8-2d-1116.dwg)
- [2 层：`3.95-01 PCB.dwg`](../../docs/86-enclosure-2-layer/3.95-01%20PCB.dwg)
- [2 层：`增加开口结构外壳20250102.dwg`](../../docs/86-enclosure-2-layer/%E5%A2%9E%E5%8A%A0%E5%BC%80%E5%8F%A3%E7%BB%93%E6%9E%84%E5%A4%96%E5%A3%B320250102.dwg)
- [2 层：`装配0718(1).DWG`](../../docs/86-enclosure-2-layer/%E8%A3%85%E9%85%8D0718(1).DWG)

### 芯片资料（乐鑫官方）

- [ESP32-S3 系列产品页（中文）](https://www.espressif.com/zh-hans/products/socs/esp32-s3)
- [ESP32-S3 系列产品页（英文）](https://www.espressif.com/en/products/socs/esp32-s3)
- [ESP-IDF 编程指南 · ESP32-S3（中文）](https://docs.espressif.com/projects/esp-idf/zh_CN/latest/esp32s3/index.html)
- [ESP-IDF Programming Guide · ESP32-S3（English）](https://docs.espressif.com/projects/esp-idf/en/latest/esp32s3/index.html)

## 购买链接

<p align="center">
  
  &nbsp;&nbsp;
  
</p>

**国内（淘宝）**

- 店铺：[鱼鹰光电工厂店](https://shop110742373.taobao.com/)

**海外（AliExpress）**

- 店铺：[OSPTEK Official Store](https://www.aliexpress.com/store/1105701619)

---

## 技术支持

如有技术问题或合作需求，欢迎通过以下方式联系我们：

- 技术支持 / 产品咨询：<luyu@osptek.com>
- QQ 技术交流群：**985881096**
- 公司官网：<https://osptek.com/>
- 有任何问题，都可以在本仓库 Issues 中提问

---

<p align="center"><sub>© 2026 OSPTEK 鱼鹰光电 · 本仓库资料采用 CC BY 4.0 许可</sub></p>

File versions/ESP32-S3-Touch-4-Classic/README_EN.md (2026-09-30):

<p align="left">OSPTEK</p>

<h1 align="center">OSPTEK ESP32-S3-Touch-4-Classic Touch Panel</h1>

<p align="center"><b>86-Type Panel · Touch UI · One RS485 Port</b></p>

<p align="center">English | <a href="./README.md">简体中文</a> · <a href="../../README_EN.md">Family index</a></p>

<p align="center">
  
  
  
  
</p>

<p align="center">OSPTEK ESP32-S3-Touch-4-Classic product image</p>

## Contents

- [Overview](#overview)
- [Features](#features)
- [Applications](#applications)
- [Specifications](#specifications)
- [Display](#display)
- [Hardware Resources](#hardware-resources)
- [Quick Start](#quick-start)
- [Examples](#examples)
- [Prebuilt Firmware](#prebuilt-firmware)
- [Repository Structure](#repository-structure)
- [Documentation](#documentation)
- [Where to Buy](#where-to-buy)
- [Support](#support)

---

## Overview

> 📌 This page is **ESP32-S3-Touch-4-Classic** (schematic: `ESP32-S3-Touch基础板V1.0`). The examples / prebuilt firmware are **verified on Classic**.

OSPTEK **ESP32-S3-Touch-4-Classic** is a **4-inch touch panel** based on an ESP32-S3 module (2.4 GHz Wi-Fi + Bluetooth LE 5), with **16 MB Flash** and **8 MB PSRAM**, and an onboard **YDP395BT009-V1** (~3.95") **480×480** RGB capacitive touch display (driver **ST7701S**).

The module is **ESP32-S3-WROOM-1-N16R8**. It includes one **RS485** port, USB Type-C (power / flash), I²C, and a buzzer—suited as a finished product for smart control panels and interactive HMI.

## Features

- **4" square touch display**: YDP395BT009-V1, 480×480, ST7701S + capacitive touch, ideal for 86-type panel UIs
- **ESP32-S3 MCU**: Wi-Fi + BLE 5, 16 MB Flash + 8 MB PSRAM
- **Industrial bus**: onboard RS485
- **Power**: USB Type-C; wide-range terminal input (see schematic)
- **Debug**: CH340K USB-UART
- **Expansion**: I²C, LCD FPC, buzzer, and more (see schematic)

## Applications

- Smart home central control / 86-type interactive panels
- Home gateway and local HMI
- Industrial control and device status displays
- Smart lighting and building panels

## Specifications

### MCU & Memory

| Item | Specification |
| ---- | --- |
| Product model | ESP32-S3-Touch-4-Classic |
| Board / schematic | ESP32-S3-Touch Standard board V1.0 |
| Module | ESP32-S3-WROOM-1-N16R8 |
| Flash | 16 MB |
| PSRAM | 8 MB |
| Wireless | 2.4 GHz Wi-Fi, Bluetooth LE 5 |

### Display & Touch

Summary below; full module parameters, driver, and touch details are in [Display](#display).

| Item | Specification |
| ---- | --- |
| Panel module | YDP395BT009-V1 (~3.95") |
| Resolution | 480×480 |
| Driver IC | ST7701S |
| Display interface | RGB 18-bit |
| Touch | Capacitive (FT6336U, I²C) |
| Brightness | 350 cd/m² typ. |

### Interfaces & Power

| Item | Specification |
| ---- | --- |
| USB | Type-C (power, flash) |
| USB-UART | CH340K |
| RS485 | Onboard |
| Sensor | I²C |
| Audio cue | Onboard buzzer |

Power tree and exact electrical ratings: see the [schematic](./docs/ESP32-S3-Touch基础板V1.0.pdf).

## Display

This panel uses OSPTEK TFT module **YDP395BT009-V1** with driver IC **ST7701S**, connected via the board LCD FPC. Touch is capacitive (I²C, FT6336U).

### Module Specifications (YDP395BT009-V1)

| Item | Specification |
| ---- | --- |
| Module model | YDP395BT009-V1 |
| Size | 3.95" (diagonal) |
| Display mode | Normally black |
| Resolution | 480 (H) RGB × 480 (V) |
| Dot pitch | 153 μm × 153 μm |
| Active area | 71.86 × 70.18 mm |
| Module outline | 83.85 × 83.85 × 3.27 mm |
| Color arrangement | RGB vertical stripe |
| Interface | RGB 18-bit (HSYNC / VSYNC / DE / DCLK); driver init via 3-wire SPI (SDA / SCL / CS) |
| Driver IC | ST7701S |
| Brightness | 350 cd/m² typ. (min. ~300) |
| Viewing angle | All view (typ. ~80°) |
| Contrast ratio | ~1000:1 typ. |
| Backlight | 8 white LEDs (typ. ~12 V / 40 mA) |
| Operating temp. | −20 ℃ ~ +70 ℃ |
| Storage temp. | −30 ℃ ~ +80 ℃ |

Touch signals such as `TP_SCL` / `TP_SDA` / `TP_INT` / `TP_RESET` are brought out on the same FPC; typical touch supply is 2.8–3.3 V.

### Display Documents

- [Panel datasheet YDP395BT009-V1 (PDF)](./docs/YDP395BT009-V1.pdf)
- [Assembly CAD (YDP395BT009-V1)](./docs/YDP395BT009-V1.dwg)
- [Driver IC ST7701S datasheet (PDF)](./docs/ST7701S_SPEC_V1.3.pdf)
- [Touch IC FT6336U datasheet (PDF)](./docs/FT6336U_DataSheet_V1.1.pdf)
- [Init sequence (text)](./docs/BOE3.95_480x480_ST7701S_init.txt)

## Hardware Resources

### Onboard Overview

| Resource | Description |
| --- | --- |
| ESP32-S3-WROOM-1-N16R8 | Wi-Fi + BLE MCU module |
| RS485 | Onboard transceiver |
| USB bridge | CH340K |
| LCD connector | FPC to the LCD |
| Buzzer | Onboard |

### Schematic

- [ESP32-S3-Touch Standard board V1.0 schematic (PDF)](./docs/ESP32-S3-Touch基础板V1.0.pdf)

## Quick Start

1. Prepare: ESP32-S3-Touch-LCD-4, a data-capable USB cable (not charge-only), and a PC (Windows / Linux / macOS).
2. Connect USB between the PC and the panel USB port.
3. **Verify the display (recommended)**: flash the prebuilt firmware in this repo—see [Prebuilt Firmware](#prebuilt-firmware).
   - On Windows, use Espressif’s graphical **[Flash Download Tools](https://www.espressif.com/en/support/download/other-tools)**.
   - Guide: [Flash Download Tool User Guide · ESP32-S3](https://docs.espressif.com/projects/esp-test-tools/en/latest/esp32s3/production_stage/tools/flash_download_tool.html)
4. **Application development**: build the [example](#examples) with ESP-IDF (auto-download via UART DTR/RTS; see schematic).

Hardware details:

- [ESP32-S3-Touch Standard board V1.0 schematic (PDF)](./docs/ESP32-S3-Touch基础板V1.0.pdf)

Espressif tools & getting started:

- [Flash Download Tools (Windows)](https://www.espressif.com/en/support/download/other-tools)
- [ESP-IDF Get Started · ESP32-S3](https://docs.espressif.com/projects/esp-idf/en/latest/esp32s3/get-started/)
- [ESP-IDF 快速入门 · ESP32-S3（中文）](https://docs.espressif.com/projects/esp-idf/zh_CN/latest/esp32s3/get-started/)

## Examples

Touch uses Espressif `i2c_master` + `esp_lcd_touch_ft5x06` (legacy `driver/i2c.h` / `i2c_driver_install` removed). Panel: RGB ST7701, 480×480.

| Description | Path |
| --- | ---- |
| ESP-IDF 5 · LVGL 8 common demo | [`examples/s3-idf5_st7701-rgb_lvgl8-common-demo/`](./examples/s3-idf5_st7701-rgb_lvgl8-common-demo/) |
| ESP-IDF 5 · LVGL 9 common demo | [`examples/s3-idf5_st7701-rgb_lvgl9-common-demo/`](./examples/s3-idf5_st7701-rgb_lvgl9-common-demo/) |
| ESP-IDF 5 · 3.95" box project (rev2) | [`examples/ESP32S3_3.95In_Box_rev2/`](./examples/ESP32S3_3.95In_Box_rev2/) |
| ESP-IDF 5 · LVGL 8 game demo | [`examples/esp32s3_st7701_lvgl-game/`](./examples/esp32s3_st7701_lvgl-game/) |
| ESP-IDF 5 · LVGL 9 Lottie player | [`examples/esp32s3-idf5_st7701-rgb_lvgl9-lottie-player/`](./examples/esp32s3-idf5_st7701-rgb_lvgl9-lottie-player/) |
| ESP-IDF 6 · LVGL 8 common demo | [`examples/esp32s3-idf6_st7701-rgb_lvgl8-common-demo/`](./examples/esp32s3-idf6_st7701-rgb_lvgl8-common-demo/) |
| ESP-IDF 6 · LVGL 9 common demo | [`examples/esp32s3-idf6_st7701-rgb_lvgl9-common-demo/`](./examples/esp32s3-idf6_st7701-rgb_lvgl9-common-demo/) |

> The examples and prebuilt firmware are verified on the **Classic** board (same panel as v1).

With the matching ESP-IDF installed (IDF 5 projects: ≥5.5; IDF 6 projects: IDF 6):

```bash
cd examples/s3-idf5_st7701-rgb_lvgl8-common-demo
idf.py set-target esp32s3
idf.py build
idf.py -p <PORT> flash monitor
```

Component dependencies are managed by each project's `main/idf_component.yml` and are fetched on the first build.

## Prebuilt Firmware

| File | Flash address | Description |
| ---- | --- | --- |
| [`firmware/esp32-s3-touch-lcd-4.bin`](./firmware/esp32-s3-touch-lcd-4.bin) | **`0x0`** | Merged image (bootloader + partition table + app), factory demo firmware |

Flash settings match the project: chip **ESP32-S3**, Flash **16 MB**, **DIO**, **80 MHz**. Write the merged package from address **`0x0`**.

### Option 1: Flash Download Tools (Windows, easiest)

1. Download and open Espressif **[Flash Download Tools](https://www.espressif.com/en/support/download/other-tools)**.
2. Set `ChipType` to **ESP32-S3**, `WorkMode` to Develop, `LoadMode` to UART.
3. Enable one row, select [`firmware/esp32-s3-touch-lcd-4.bin`](./firmware/esp32-s3-touch-lcd-4.bin), address **`0x0`** (do not use app-partition `0x10000`).
4. Set SPI SPEED / SPI MODE / FLASH SIZE as above (80 MHz, DIO, 16 MB).
5. Select the correct COM port and click **START**.

UI details: [Flash Download Tool User Guide · ESP32-S3](https://docs.espressif.com/projects/esp-test-tools/en/latest/esp32s3/production_stage/tools/flash_download_tool.html)

### Option 2: esptool (CLI)

Replace `<PORT>` with your serial port (e.g. `/dev/ttyUSB0`, `COM3`); address is **`0x0`**:

```bash
esptool.py --chip esp32s3 -p <PORT> write_flash 0x0 firmware/esp32-s3-touch-lcd-4.bin
```

## Repository layout

```text
esp32-s3-touch-lcd-4/                                # repo root (nav: ../../README_EN.md)
└── versions/
    └── ESP32-S3-Touch-4-Classic/                    # full materials for this SKU
        ├── README.md
        ├── README_EN.md
        ├── images/
        ├── docs/
        ├── firmware/
        └── examples/
```

## Documentation

### Product Documents

- [ESP32-S3-Touch Standard board V1.0 schematic (PDF)](./docs/ESP32-S3-Touch基础板V1.0.pdf)
- [Panel datasheet YDP395BT009-V1 (PDF)](./docs/YDP395BT009-V1.pdf)
- [Assembly CAD (YDP395BT009-V1)](./docs/YDP395BT009-V1.dwg)
- [Driver IC ST7701S datasheet (PDF)](./docs/ST7701S_SPEC_V1.3.pdf)
- [Touch IC FT6336U datasheet (PDF)](./docs/FT6336U_DataSheet_V1.1.pdf)
- [Init sequence (text)](./docs/BOE3.95_480x480_ST7701S_init.txt)
- [Examples](#examples)
- [Prebuilt firmware esp32-s3-touch-lcd-4.bin](./firmware/esp32-s3-touch-lcd-4.bin)

### Shared enclosure CAD

The 86-type enclosure (2-layer / 4-layer) is shared by every SKU. Files live in the repo-root `docs/` folder.

- [4-layer: `0302(1).dwg`](../../docs/86-enclosure-4-layer/0302(1).dwg)
- [4-layer: `WSD4寸-2d-1116.dwg`](../../docs/86-enclosure-4-layer/WSD4%E5%AF%B8-2d-1116.dwg)
- [2-layer: `3.95-01 PCB.dwg`](../../docs/86-enclosure-2-layer/3.95-01%20PCB.dwg)
- [2-layer: `增加开口结构外壳20250102.dwg`](../../docs/86-enclosure-2-layer/%E5%A2%9E%E5%8A%A0%E5%BC%80%E5%8F%A3%E7%BB%93%E6%9E%84%E5%A4%96%E5%A3%B320250102.dwg)
- [2-layer: `装配0718(1).DWG`](../../docs/86-enclosure-2-layer/%E8%A3%85%E9%85%8D0718(1).DWG)

### Chip Documents (Espressif)

- [ESP32-S3 product page](https://www.espressif.com/en/products/socs/esp32-s3)
- [ESP32-S3 系列产品页（中文）](https://www.espressif.com/zh-hans/products/socs/esp32-s3)
- [ESP-IDF Programming Guide · ESP32-S3](https://docs.espressif.com/projects/esp-idf/en/latest/esp32s3/index.html)
- [ESP-IDF 编程指南 · ESP32-S3（中文）](https://docs.espressif.com/projects/esp-idf/zh_CN/latest/esp32s3/index.html)

## Where to Buy

<p align="center">
  
  &nbsp;&nbsp;
  
</p>

**International (AliExpress)**

- Store: [OSPTEK Official Store](https://www.aliexpress.com/store/1105701619)

**China (Taobao)**

- Store: [鱼鹰光电工厂店](https://shop110742373.taobao.com/)

---

## Support

For technical questions or business inquiries:

- Technical support / product inquiry: <luyu@osptek.com>
- QQ technical group: **985881096**
- Website: <https://osptek.com/>
- Feel free to open an Issue in this repository if you have any questions

---

<p align="center"><sub>© 2026 OSPTEK · Materials in this repository are licensed under CC BY 4.0</sub></p>

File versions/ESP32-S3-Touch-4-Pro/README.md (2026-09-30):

<p align="left">OSPTEK</p>

<h1 align="center">OSPTEK ESP32-S3-Touch-4-Pro 触摸屏面板</h1>

<p align="center"><b>86 型面板 · 触摸交互 · RS485 · 板载音频</b></p>

<p align="center"><a href="./README_EN.md">English</a> | 简体中文 · <a href="../../README.md">系列索引</a></p>

<p align="center">
  
  
  
  
</p>

<p align="center">OSPTEK ESP32-S3-Touch-4-Pro 产品宣传图</p>

## 目录

- [产品简介](#产品简介)
- [产品特性](#产品特性)
- [规格参数](#规格参数)
- [屏幕](#屏幕)
- [硬件资源](#硬件资源)
- [示例工程](#示例工程)
- [仓库结构](#仓库结构)
- [相关资料](#相关资料)
- [购买链接](#购买链接)
- [技术支持](#技术支持)

---

## 产品简介

> 📌 本文档对应 **ESP32-S3-Touch-4-Pro**（原理图：`ESP32-S3-Touch-Pro_V1.1`）。

OSPTEK **ESP32-S3-Touch-4-Pro** 在 Classic 基础能力之上，增加板载音频链路（**ES8311**、功放 **NS4150B**、MIC / SPEAKER），适合需要本地语音交互的中控面板场景。

主控模组同为 **ESP32-S3-WROOM-1-N16R8**，板载 **RS485**、USB Type-C、I²C 等接口。

## 产品特性

- **4 寸方屏触摸**：YDP395BT009-V1，480×480，ST7701S + 电容触摸
- **ESP32-S3 主控**：Wi-Fi + BLE 5，16 MB Flash + 8 MB PSRAM
- **Pro 音频**：ES8311 + NS4150B，麦克风 / 喇叭通路
- **工业总线**：板载 RS485（THVD1406DR）
- **调试**：CH340K USB 转串口
- **隔离 I/O**：光耦隔离数字输入 / 输出；PCA9557 I²C 扩展

## 规格参数

### 主控与存储

| 项目 | 规格 |
| ---- | ---- |
| 产品型号 | ESP32-S3-Touch-4-Pro |
| 主板 / 原理图 | ESP32-S3-Touch-Pro V1.1 |
| 主控模组 | ESP32-S3-WROOM-1-N16R8 |
| Flash | 16 MB |
| PSRAM | 8 MB |
| 无线 | 2.4 GHz Wi-Fi、Bluetooth LE 5 |

### 显示与触摸

| 项目 | 规格 |
| ---- | ---- |
| 屏模组 | YDP395BT009-V1（约 3.95 英寸） |
| 分辨率 | 480×480 |
| 驱动 IC | ST7701S |
| 显示接口 | RGB 18-bit |
| 触摸 | 电容触摸（FT6336U，I²C） |
| 亮度 | 典型 350 cd/m² |

完整模组参数见下方 [屏幕](#屏幕)。

### 音频（Pro）

| 项目 | 规格 |
| ---- | ---- |
| 编解码 | ES8311 |
| 功放 | NS4150B |
| 输入 / 输出 | MIC、SPEAKER |

### 接口

| 项目 | 规格 |
| ---- | ---- |
| USB | Type-C |
| USB 转串口 | CH340K |
| RS485 | THVD1406DR |
| 传感器 / 扩展 | I²C（含 PCA9557） |
| 隔离 I/O | 光耦数字输入 / 输出 |

引脚与电源树见 [原理图](./docs/ESP32-S3-Touch-Pro_V1.1.pdf)。

## 屏幕

本面板搭载 OSPTEK 自产 TFT 模组 **YDP395BT009-V1**，驱动 IC 为 **ST7701S**，通过主板 LCD FPC 连接；触摸为电容方案（I²C，FT6336U）。

### 模组规格（YDP395BT009-V1）

| 项目 | 规格 |
| ---- | ---- |
| 模组型号 | YDP395BT009-V1 |
| 尺寸 | 3.95 英寸（对角线） |
| 显示模式 | Normally Black |
| 分辨率 | 480（H）RGB × 480（V） |
| 点距 | 153 μm × 153 μm |
| 有效显示区 | 71.86 × 70.18 mm |
| 模组外形 | 83.85 × 83.85 × 3.27 mm |
| 排列 | RGB 垂直条纹 |
| 接口 | RGB 18-bit（含 HSYNC / VSYNC / DE / DCLK）；驱动初始化为 3-wire SPI（SDA / SCL / CS） |
| 驱动 IC | ST7701S |
| 亮度 | 典型 350 cd/m²（最小约 300） |
| 视角 | 全视角（典型约 80°） |
| 对比度 | 典型约 1000:1 |
| 背光 | 8 颗白光 LED（背光供电典型约 12 V / 40 mA） |
| 工作温度 | −20 ℃ ~ +70 ℃ |
| 存储温度 | −30 ℃ ~ +80 ℃ |

触摸侧经同一 FPC 引出 `TP_SCL` / `TP_SDA` / `TP_INT` / `TP_RESET` 等信号，供电典型 2.8–3.3 V。

### 屏幕相关资料

- [屏模组规格书 YDP395BT009-V1（PDF）](./docs/YDP395BT009-V1.pdf)
- [总成图 CAD（YDP395BT009-V1）](./docs/YDP395BT009-V1.dwg)
- [驱动 IC ST7701S Datasheet（PDF）](./docs/ST7701S_SPEC_V1.3.pdf)
- [触摸 IC FT6336U Datasheet（PDF）](./docs/FT6336U_DataSheet_V1.1.pdf)
- [初始化序列（文本）](./docs/BOE3.95_480x480_ST7701S_init.txt)

## 硬件资源

### 外观

<p align="center">
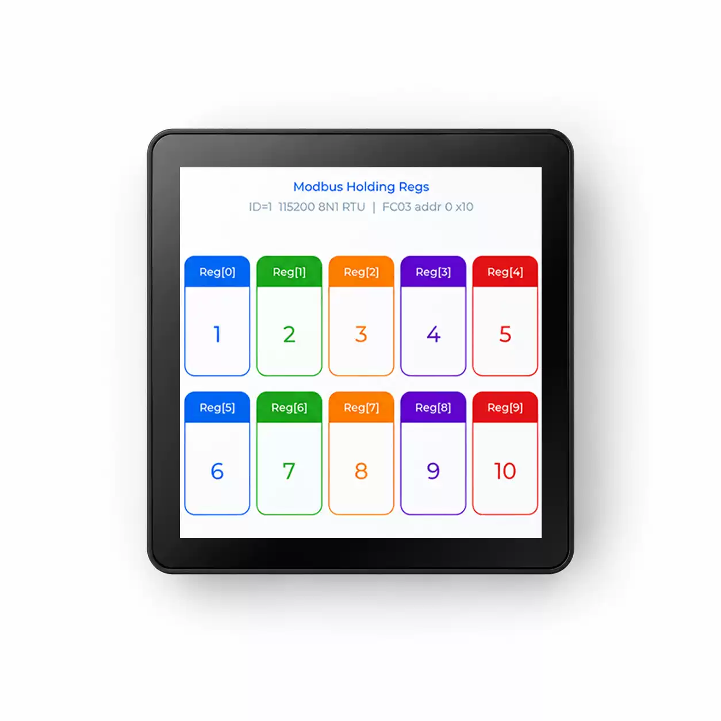
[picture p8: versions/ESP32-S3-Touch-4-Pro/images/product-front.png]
ESP32-S3-Touch-4-Pro 正面
  
  &nbsp;&nbsp;
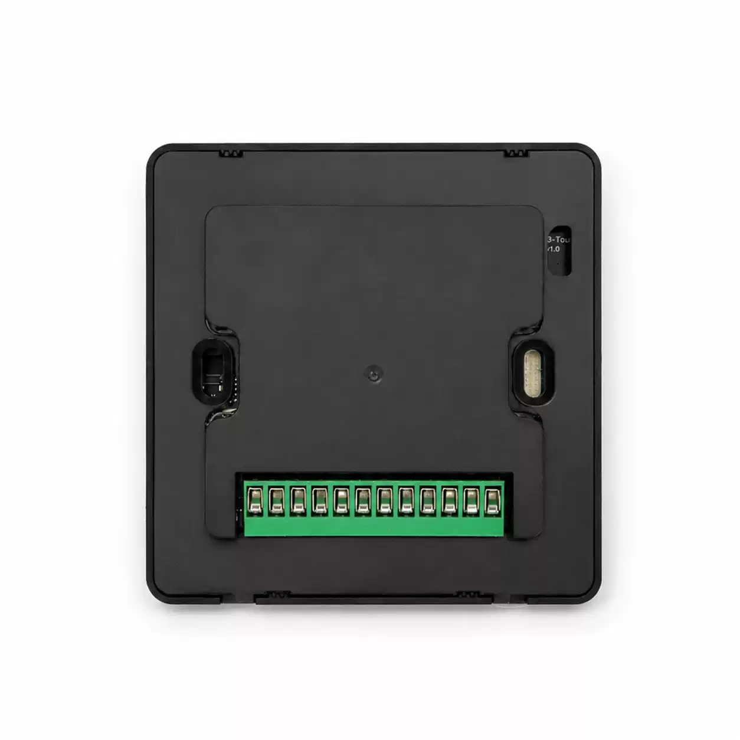
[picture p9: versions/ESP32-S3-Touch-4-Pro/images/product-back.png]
ESP32-S3-Touch-4-Pro 背面
  
</p>

### 板载资源概览

| 资源 | 说明 |
| ---- | ---- |
| ESP32-S3-WROOM-1-N16R8 | Wi-Fi + BLE MCU 模组 |
| CH340K | USB 转串口 |
| THVD1406DR | RS485 收发 |
| PCA9557 | I²C I/O 扩展 |
| ES8311 + NS4150 | 音频编解码 / 功放 |
| 光耦 | 隔离数字输入 / 输出 |
| USB Type-C | 供电 / 烧录 |
| 接线端子 | 外部电源与总线接口 |

### 接口标注

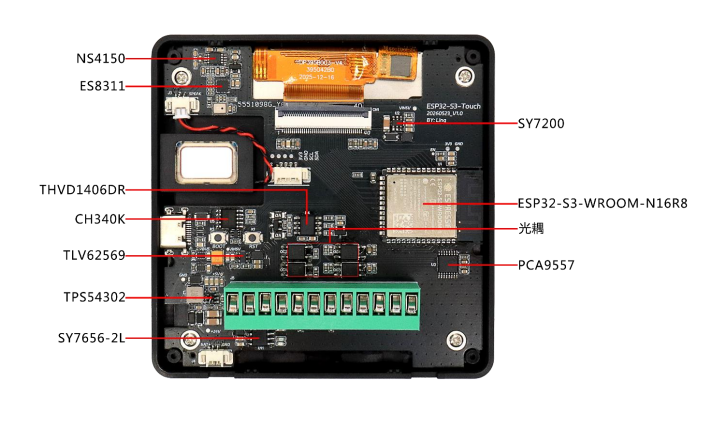
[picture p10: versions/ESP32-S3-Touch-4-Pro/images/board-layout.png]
ESP32-S3-Touch-4-Pro 主板接口与器件标注


更完整的文字说明见[产品说明书](./docs/ESP32-S3-Touch-Pro%204%E5%AF%B8WiFi%E4%B8%B2%E5%8F%A3%E5%B1%8F20260604.pdf)。

### 原理图

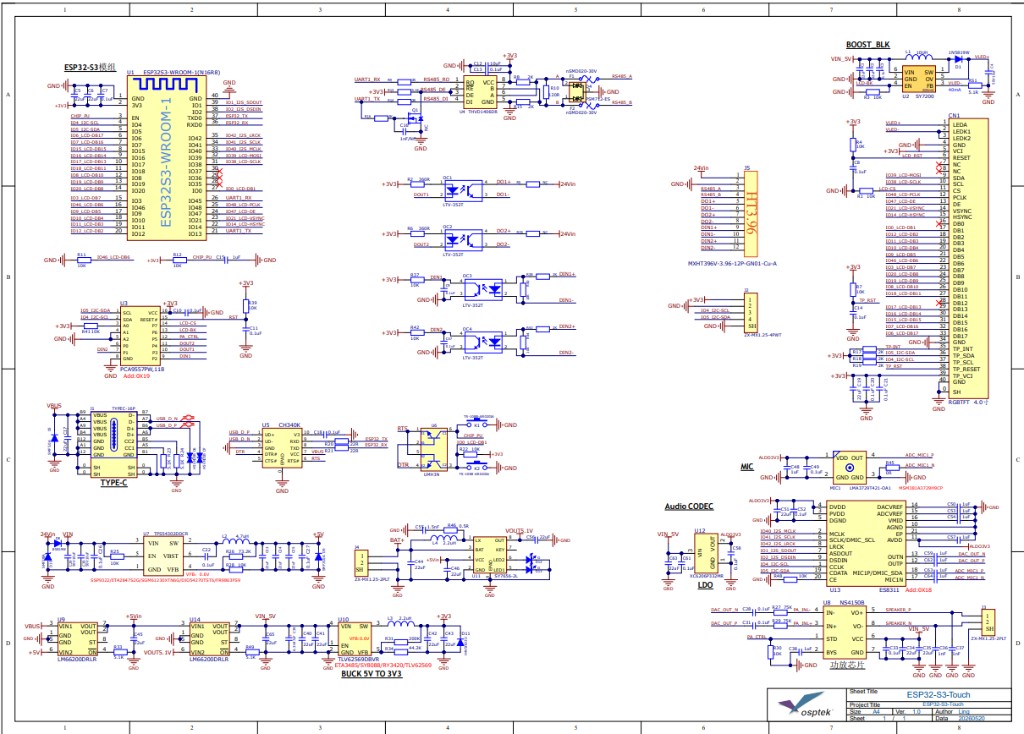
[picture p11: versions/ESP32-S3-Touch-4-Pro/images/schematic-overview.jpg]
ESP32-S3-Touch-4-Pro 原理图预览


完整 PDF：

- [ESP32-S3-Touch-Pro V1.1 原理图（PDF）](./docs/ESP32-S3-Touch-Pro_V1.1.pdf)

## 示例工程

本型号专用演示：RGB ST7701（480×480）+ FT6336U 触摸、RS485 Modbus、PCA9557。

| 说明 | 路径 |
| ---- | ---- |
| ESP32-S3-Touch-4-Pro Demo（LVGL 9 · RS485 Modbus） | [`examples/esp32-s3-touch-lcd-4-pro-demo/`](./examples/esp32-s3-touch-lcd-4-pro-demo/) |

在已安装 ESP-IDF 的环境下：

```bash
cd examples/esp32-s3-touch-lcd-4-pro-demo
idf.py set-target esp32s3
idf.py build
idf.py -p <串口> flash monitor
```

组件依赖由 `main/idf_component.yml` 管理，首次编译会自动拉取。

## 仓库结构

```text
esp32-s3-touch-lcd-4/                                # 仓库根（导航见 ../../README.md）
└── versions/
    └── ESP32-S3-Touch-4-Pro/                        # 本型号完整资料
        ├── README.md
        ├── README_EN.md
        ├── images/
        ├── docs/
        └── examples/
```

## 相关资料

- [产品说明书（PDF）](./docs/ESP32-S3-Touch-Pro%204%E5%AF%B8WiFi%E4%B8%B2%E5%8F%A3%E5%B1%8F20260604.pdf)
- [ESP32-S3-Touch-Pro V1.1 原理图（PDF）](./docs/ESP32-S3-Touch-Pro_V1.1.pdf)
- [屏模组规格书 YDP395BT009-V1（PDF）](./docs/YDP395BT009-V1.pdf)
- [总成图 CAD（YDP395BT009-V1）](./docs/YDP395BT009-V1.dwg)
- [驱动 IC ST7701S Datasheet（PDF）](./docs/ST7701S_SPEC_V1.3.pdf)
- [触摸 IC FT6336U Datasheet（PDF）](./docs/FT6336U_DataSheet_V1.1.pdf)
- [初始化序列（文本）](./docs/BOE3.95_480x480_ST7701S_init.txt)
- [示例工程](#示例工程)
- [ESP32-S3-Touch-4-Classic](../ESP32-S3-Touch-4-Classic/)

### 系列通用外壳 CAD

86 型外壳（2 层 / 4 层）全型号通用，文件在仓库根 `docs/`。

- [4 层：`0302(1).dwg`](../../docs/86-enclosure-4-layer/0302(1).dwg)
- [4 层：`WSD4寸-2d-1116.dwg`](../../docs/86-enclosure-4-layer/WSD4%E5%AF%B8-2d-1116.dwg)
- [2 层：`3.95-01 PCB.dwg`](../../docs/86-enclosure-2-layer/3.95-01%20PCB.dwg)
- [2 层：`增加开口结构外壳20250102.dwg`](../../docs/86-enclosure-2-layer/%E5%A2%9E%E5%8A%A0%E5%BC%80%E5%8F%A3%E7%BB%93%E6%9E%84%E5%A4%96%E5%A3%B320250102.dwg)
- [2 层：`装配0718(1).DWG`](../../docs/86-enclosure-2-layer/%E8%A3%85%E9%85%8D0718(1).DWG)

### 芯片资料（乐鑫官方）

- [ESP32-S3 系列产品页（中文）](https://www.espressif.com/zh-hans/products/socs/esp32-s3)
- [ESP-IDF 编程指南 · ESP32-S3（中文）](https://docs.espressif.com/projects/esp-idf/zh_CN/latest/esp32s3/index.html)

## 购买链接

<p align="center">
  
  &nbsp;&nbsp;
  
</p>

**国内（淘宝）**

- 店铺：[鱼鹰光电工厂店](https://shop110742373.taobao.com/)

**海外（AliExpress）**

- 店铺：[OSPTEK Official Store](https://www.aliexpress.com/store/1105701619)

---

## 技术支持

- 技术支持 / 产品咨询：<luyu@osptek.com>
- QQ 技术交流群：**985881096**
- 公司官网：<https://osptek.com/>
- 有任何问题，都可以在本仓库 Issues 中提问

---

<p align="center"><sub>© 2026 OSPTEK 鱼鹰光电 · 本仓库资料采用 CC BY 4.0 许可</sub></p>

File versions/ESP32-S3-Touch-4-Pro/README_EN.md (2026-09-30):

<p align="left">OSPTEK</p>

<h1 align="center">OSPTEK ESP32-S3-Touch-4-Pro Touch Panel</h1>

<p align="center"><b>86-Type Panel · Touch UI · RS485 · Onboard Audio</b></p>

<p align="center">English | <a href="./README.md">简体中文</a> · <a href="../../README_EN.md">Family index</a></p>

<p align="center">
  
  
  
  
</p>

<p align="center">OSPTEK ESP32-S3-Touch-4-Pro product image</p>

## Contents

- [Overview](#overview)
- [Other SKUs in this series](#other-skus-in-this-series)
- [Features](#features)
- [Specifications](#specifications)
- [Display](#display)
- [Hardware Resources](#hardware-resources)
- [Examples](#examples)
- [Repository Structure](#repository-structure)
- [Documentation](#documentation)
- [Where to Buy](#where-to-buy)
- [Support](#support)

---

## Overview

> 📌 This page is **ESP32-S3-Touch-4-Pro** (schematic: `ESP32-S3-Touch-Pro_V1.1`).

OSPTEK **ESP32-S3-Touch-4-Pro** adds an onboard audio path (**ES8311**, amp **NS4150B**, MIC / SPEAKER) on top of the Classic feature set.

Module: **ESP32-S3-WROOM-1-N16R8**, with **RS485**, USB Type-C, I²C, and more.

## Features

- **4" square touch panel**: YDP395BT009-V1, 480×480, ST7701S + capacitive touch
- **ESP32-S3**: Wi-Fi + BLE 5, 16 MB Flash + 8 MB PSRAM
- **Pro audio**: ES8311 + NS4150B, microphone / speaker
- **RS485** onboard (THVD1406DR)
- **Debug**: CH340K USB-UART
- **Isolated I/O**: optocoupler digital I/O; PCA9557 I²C expander

## Specifications

### MCU & Memory

| Item | Specification |
| ---- | --- |
| Product | ESP32-S3-Touch-4-Pro |
| Board / schematic | ESP32-S3-Touch-Pro V1.1 |
| Module | ESP32-S3-WROOM-1-N16R8 |
| Flash | 16 MB |
| PSRAM | 8 MB |
| Wireless | 2.4 GHz Wi-Fi, Bluetooth LE 5 |

### Display & Touch

| Item | Specification |
| ---- | --- |
| Panel module | YDP395BT009-V1 (~3.95") |
| Resolution | 480×480 |
| Driver IC | ST7701S |
| Display interface | RGB 18-bit |
| Touch | Capacitive (FT6336U, I²C) |
| Brightness | 350 cd/m² typ. |

Full module details are in [Display](#display) below.

### Audio (Pro)

| Item | Specification |
| ---- | --- |
| Codec | ES8311 |
| Amplifier | NS4150B |
| I/O | MIC, SPEAKER |

### Interfaces

| Item | Specification |
| ---- | --- |
| USB | Type-C |
| USB-UART | CH340K |
| RS485 | THVD1406DR |
| Sensor / expand | I²C (incl. PCA9557) |
| Isolated I/O | Optocoupler digital I/O |

Pinout and power tree: see the [schematic](./docs/ESP32-S3-Touch-Pro_V1.1.pdf).

## Display

This panel uses OSPTEK TFT module **YDP395BT009-V1**, driver IC **ST7701S**, connected via the LCD FPC; touch is capacitive (I²C, FT6336U).

### Module Specs (YDP395BT009-V1)

| Item | Specification |
| ---- | --- |
| Module | YDP395BT009-V1 |
| Size | 3.95" diagonal |
| Display mode | Normally Black |
| Resolution | 480 (H) RGB × 480 (V) |
| Pixel pitch | 153 μm × 153 μm |
| Active area | 71.86 × 70.18 mm |
| Module outline | 83.85 × 83.85 × 3.27 mm |
| Arrangement | RGB vertical stripe |
| Interface | RGB 18-bit (HSYNC / VSYNC / DE / DCLK); init via 3-wire SPI (SDA / SCL / CS) |
| Driver IC | ST7701S |
| Brightness | 350 cd/m² typ. (min. ~300) |
| Viewing angle | All view (~80° typ.) |
| Contrast | ~1000:1 typ. |
| Backlight | 8 white LEDs (~12 V / 40 mA typ.) |
| Operating temp. | −20 ℃ ~ +70 ℃ |
| Storage temp. | −30 ℃ ~ +80 ℃ |

Touch signals `TP_SCL` / `TP_SDA` / `TP_INT` / `TP_RESET` share the same FPC; supply typically 2.8–3.3 V.

### Display Documents

- [Panel datasheet YDP395BT009-V1 (PDF)](./docs/YDP395BT009-V1.pdf)
- [Assembly CAD (YDP395BT009-V1)](./docs/YDP395BT009-V1.dwg)
- [Driver IC ST7701S datasheet (PDF)](./docs/ST7701S_SPEC_V1.3.pdf)
- [Touch IC FT6336U datasheet (PDF)](./docs/FT6336U_DataSheet_V1.1.pdf)
- [Init sequence (text)](./docs/BOE3.95_480x480_ST7701S_init.txt)

## Hardware Resources

### Appearance

<p align="center">
  ESP32-S3-Touch-4-Pro front
  &nbsp;&nbsp;
  ESP32-S3-Touch-4-Pro back
</p>

### Onboard Resources

| Resource | Notes |
| --- | ----- |
| ESP32-S3-WROOM-1-N16R8 | Wi-Fi + BLE MCU module |
| CH340K | USB-UART |
| THVD1406DR | RS485 transceiver |
| PCA9557 | I²C I/O expander |
| ES8311 + NS4150 | Audio codec / amp |
| Optocouplers | Isolated digital I/O |
| USB Type-C | Power / flash |
| Terminal block | External power and bus |

### Board Layout

<p align="center">ESP32-S3-Touch-4-Pro board layout</p>

For a fuller write-up, see the [product manual](./docs/ESP32-S3-Touch-Pro%204%E5%AF%B8WiFi%E4%B8%B2%E5%8F%A3%E5%B1%8F20260604.pdf).

### Schematic

<p align="center">ESP32-S3-Touch-4-Pro schematic overview</p>

Full PDF:

- [ESP32-S3-Touch-Pro V1.1 schematic (PDF)](./docs/ESP32-S3-Touch-Pro_V1.1.pdf)

## Examples

Pro-only demo: RGB ST7701 (480×480) + FT6336U touch, RS485 Modbus, and PCA9557.

| Description | Path |
| --- | ---- |
| ESP32-S3-Touch-4-Pro demo (LVGL 9 · RS485 Modbus) | [`examples/esp32-s3-touch-lcd-4-pro-demo/`](./examples/esp32-s3-touch-lcd-4-pro-demo/) |

With ESP-IDF installed:

```bash
cd examples/esp32-s3-touch-lcd-4-pro-demo
idf.py set-target esp32s3
idf.py build
idf.py -p <PORT> flash monitor
```

Component dependencies are managed by `main/idf_component.yml` and are fetched on the first build.

## Repository layout

```text
esp32-s3-touch-lcd-4/                                # repo root (nav: ../../README_EN.md)
└── versions/
    └── ESP32-S3-Touch-4-Pro/                        # full materials for this SKU
        ├── README.md
        ├── README_EN.md
        ├── images/
        ├── docs/
        └── examples/
```

## Documentation

- [Product manual (PDF)](./docs/ESP32-S3-Touch-Pro%204%E5%AF%B8WiFi%E4%B8%B2%E5%8F%A3%E5%B1%8F20260604.pdf)
- [ESP32-S3-Touch-Pro V1.1 schematic (PDF)](./docs/ESP32-S3-Touch-Pro_V1.1.pdf)
- [Panel datasheet YDP395BT009-V1 (PDF)](./docs/YDP395BT009-V1.pdf)
- [Assembly CAD (YDP395BT009-V1)](./docs/YDP395BT009-V1.dwg)
- [Driver IC ST7701S datasheet (PDF)](./docs/ST7701S_SPEC_V1.3.pdf)
- [Touch IC FT6336U datasheet (PDF)](./docs/FT6336U_DataSheet_V1.1.pdf)
- [Init sequence (text)](./docs/BOE3.95_480x480_ST7701S_init.txt)
- [Examples](#examples)
- [ESP32-S3-Touch-4-Classic](../ESP32-S3-Touch-4-Classic/)

### Shared enclosure CAD

The 86-type enclosure (2-layer / 4-layer) is shared by every SKU. Files live in the repo-root `docs/` folder.

- [4-layer: `0302(1).dwg`](../../docs/86-enclosure-4-layer/0302(1).dwg)
- [4-layer: `WSD4寸-2d-1116.dwg`](../../docs/86-enclosure-4-layer/WSD4%E5%AF%B8-2d-1116.dwg)
- [2-layer: `3.95-01 PCB.dwg`](../../docs/86-enclosure-2-layer/3.95-01%20PCB.dwg)
- [2-layer: `增加开口结构外壳20250102.dwg`](../../docs/86-enclosure-2-layer/%E5%A2%9E%E5%8A%A0%E5%BC%80%E5%8F%A3%E7%BB%93%E6%9E%84%E5%A4%96%E5%A3%B320250102.dwg)
- [2-layer: `装配0718(1).DWG`](../../docs/86-enclosure-2-layer/%E8%A3%85%E9%85%8D0718(1).DWG)

## Where to Buy

<p align="center">
  
  &nbsp;&nbsp;
  
</p>

**International (AliExpress)**

- Store: [OSPTEK Official Store](https://www.aliexpress.com/store/1105701619)

**China (Taobao)**

- Store: [鱼鹰光电工厂店](https://shop110742373.taobao.com/)

---

## Support

- Technical support / product inquiry: <luyu@osptek.com>
- QQ technical group: **985881096**
- Website: <https://osptek.com/>
- Feel free to open an Issue in this repository if you have any questions

---

<p align="center"><sub>© 2026 OSPTEK · Materials in this repository are licensed under CC BY 4.0</sub></p>

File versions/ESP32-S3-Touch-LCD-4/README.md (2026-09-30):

<p align="left">OSPTEK</p>

<h1 align="center">OSPTEK ESP32-S3-Touch-LCD-4 触摸屏面板</h1>

<p align="center"><b>86 型面板 · 触摸交互 · 一路 RS485</b></p>

<p align="center"><a href="./README_EN.md">English</a> | 简体中文 · <a href="../../README.md">系列索引</a></p>

<p align="center">
  
  
  
  
  
</p>

<p align="center">OSPTEK ESP32-S3-Touch-LCD-4 产品宣传图</p>

## 目录

- [产品简介](#产品简介)
- [产品特性](#产品特性)
- [应用场景](#应用场景)
- [规格参数](#规格参数)
- [屏幕](#屏幕)
- [硬件资源](#硬件资源)
- [快速开始](#快速开始)
- [示例工程](#示例工程)
- [预编译固件](#预编译固件)
- [仓库结构](#仓库结构)
- [相关资料](#相关资料)
- [购买链接](#购买链接)
- [技术支持](#技术支持)

---

## 产品简介

OSPTEK **ESP32-S3-Touch-LCD-4** 是一款搭载 ESP32-S3（2.4 GHz Wi-Fi + Bluetooth LE 5）模组的 **4 英寸触摸屏面板**，集成 **16 MB Flash** 与 **8 MB PSRAM**，板载 **YDP395BT009-V1**（约 3.95"）**480×480** RGB 电容触摸屏（驱动 **ST7701S**）。

主板型号为 **ESP32-TPCB4**，主控模组为 **ESP32-S3-WROOM-1-N16R8**，板载一路 **RS485**、USB Type-C（供电 / 烧录 / 充电）、I²C 传感器接口与蜂鸣器，适合作为智能中控、交互面板等方案的整机形态产品。

## 产品特性

- **4 寸方屏触摸**：YDP395BT009-V1，480×480，ST7701S + 电容触摸，适合 86 型面板人机界面
- **ESP32-S3 主控**：Wi-Fi + BLE 5，16 MB Flash + 8 MB PSRAM
- **工业总线**：板载 RS485（SP3485EEN + 自动收发），便于接入现场设备
- **供电灵活**：USB Type-C 提供 5 V 主电源；接线端口支持 **12–24 VDC** 宽压输入（经 DCDC 降压）
- **电池管理**：集成 IP5306 充放电管理，支持电池应用场景
- **调试方便**：CH340K USB 转串口，支持自动下载（DTR/RTS 控制 EN / IO0）
- **扩展接口**：I²C 传感器口、LCD FPC 连接器、蜂鸣器等板载外设

## 应用场景

- 智能家居中控 / 86 型交互面板
- 家庭网关与本地人机界面
- 工业控制与设备状态显示
- 智能灯控与楼宇面板

## 规格参数

### 主控与存储

| 项目 | 规格 |
| ---- | ---- |
| 产品型号 | ESP32-S3-Touch-LCD-4 |
| 主板 | ESP32-TPCB4 |
| 主控模组 | ESP32-S3-WROOM-1-N16R8 |
| Flash | 16 MB |
| PSRAM | 8 MB |
| 无线 | 2.4 GHz Wi-Fi、Bluetooth LE 5 |

### 显示与触摸

概览如下；完整模组参数、驱动与触摸说明见 [屏幕](#屏幕)。

| 项目 | 规格 |
| ---- | ---- |
| 屏模组 | YDP395BT009-V1（约 3.95 英寸） |
| 分辨率 | 480×480 |
| 驱动 IC | ST7701S |
| 显示接口 | RGB 18-bit |
| 触摸 | 电容触摸（FT6336U，I²C） |
| 亮度 | 典型 350 cd/m² |

### 接口与电源

| 项目 | 规格 |
| ---- | ---- |
| USB | Type-C（供电、烧录、充电） |
| USB 转串口 | CH340K（最高约 2 Mbaud） |
| RS485 | SP3485EEN，半双工；SN74HC14PWR 实现自动收发 |
| 接线口 | 5.08 mm 4 pin |
| 传感器 | I²C |
| 听觉 | 板载蜂鸣器 |
| USB 供电 | 5 V |
| 接线端口供电 | 12–24 VDC（板载 DCDC 转 5 V） |
| 电源管理 | IP5306（约 2.1 A 充 / 2.4 A 放） |

## 屏幕

本面板搭载 OSPTEK 自产 TFT 模组 **YDP395BT009-V1**，驱动 IC 为 **ST7701S**，通过主板 LCD FPC 连接；触摸为电容方案（I²C，FT6336U）。

### 模组规格（YDP395BT009-V1）

| 项目 | 规格 |
| ---- | ---- |
| 模组型号 | YDP395BT009-V1 |
| 尺寸 | 3.95 英寸（对角线） |
| 显示模式 | Normally Black |
| 分辨率 | 480（H）RGB × 480（V） |
| 点距 | 153 μm × 153 μm |
| 有效显示区 | 71.86 × 70.18 mm |
| 模组外形 | 83.85 × 83.85 × 3.27 mm |
| 排列 | RGB 垂直条纹 |
| 接口 | RGB 18-bit（含 HSYNC / VSYNC / DE / DCLK）；驱动初始化为 3-wire SPI（SDA / SCL / CS） |
| 驱动 IC | ST7701S |
| 亮度 | 典型 350 cd/m²（最小约 300） |
| 视角 | 全视角（典型约 80°） |
| 对比度 | 典型约 1000:1 |
| 背光 | 8 颗白光 LED（背光供电典型约 12 V / 40 mA） |
| 工作温度 | −20 ℃ ~ +70 ℃ |
| 存储温度 | −30 ℃ ~ +80 ℃ |

触摸侧经同一 FPC 引出 `TP_SCL` / `TP_SDA` / `TP_INT` / `TP_RESET` 等信号，供电典型 2.8–3.3 V。

### 屏幕相关资料

- [屏模组规格书 YDP395BT009-V1（PDF）](./docs/YDP395BT009-V1.pdf)
- [总成图 CAD（YDP395BT009-V1）](./docs/YDP395BT009-V1.dwg)
- [驱动 IC ST7701S Datasheet（PDF）](./docs/ST7701S_SPEC_V1.3.pdf)
- [触摸 IC FT6336U Datasheet（PDF）](./docs/FT6336U_DataSheet_V1.1.pdf)
- [初始化序列（文本）](./docs/BOE3.95_480x480_ST7701S_init.txt)

## 硬件资源

### 板载资源概览

| 资源 | 说明 |
| ---- | ---- |
| ESP32-S3-WROOM-1-N16R8 | Wi-Fi + BLE MCU 模组 |
| 电源指示灯 | 工作时红色亮起 |
| RS485 收发 | SP3485EEN + 自动收发电路 |
| USB 转换 | CH340K |
| DCDC | SGM6132，宽压输入转 5 V |
| LCD 连接器 | 0.5 mm 间距 FPC，连接 LCD |
| 蜂鸣器 | 板载听觉提示 |

### 接口标注

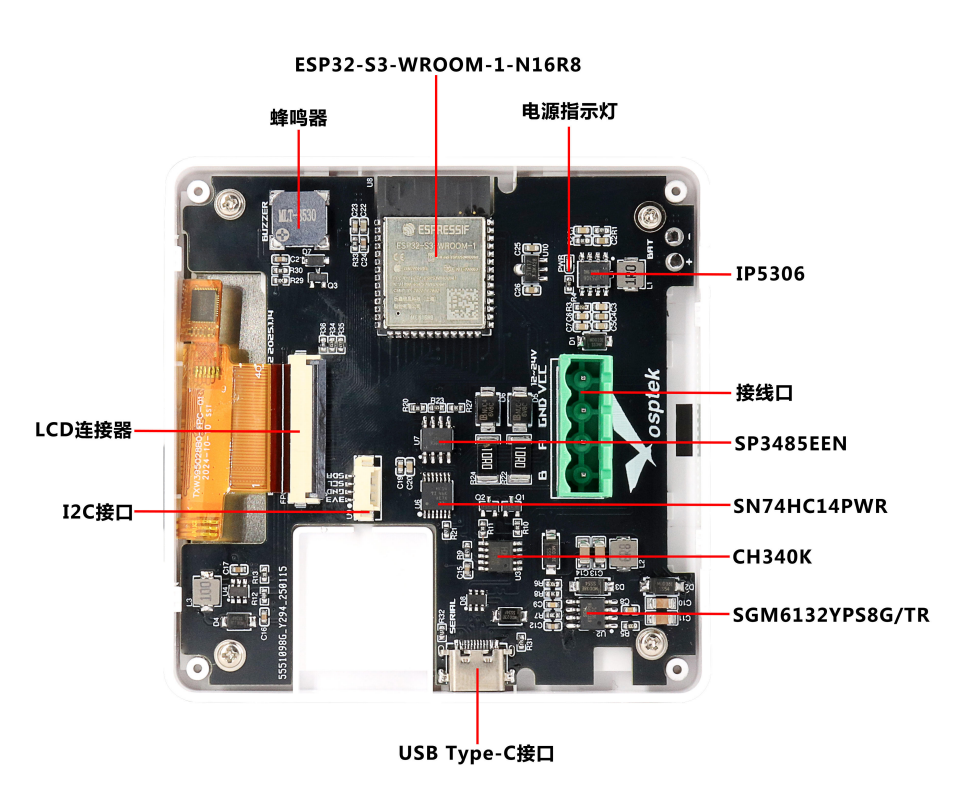
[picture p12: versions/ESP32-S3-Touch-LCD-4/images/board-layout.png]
ESP32-S3-Touch-LCD-4 主板接口与器件标注


更完整的文字说明见[使用指南](./docs/ESP32-S3-Touch-LCD-4_使用指南2025.3.14.pdf)。

### 原理图

预览（节选）：

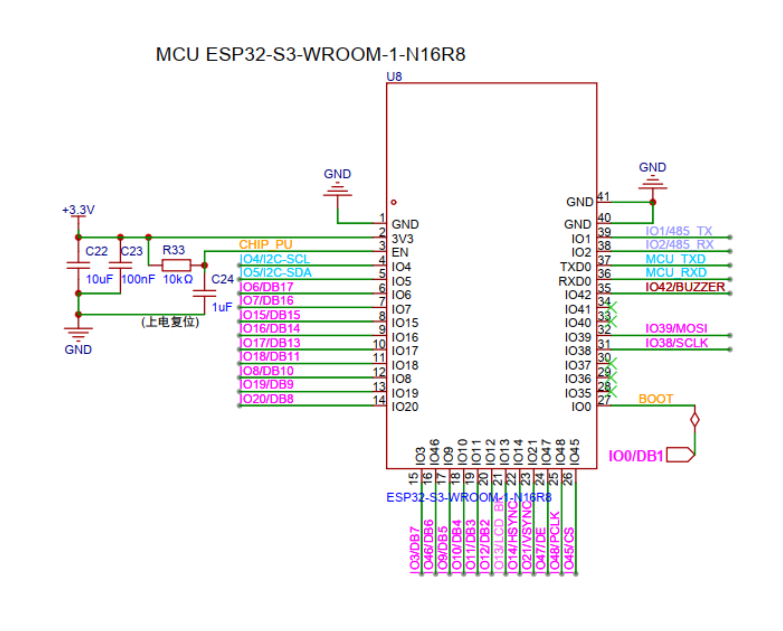
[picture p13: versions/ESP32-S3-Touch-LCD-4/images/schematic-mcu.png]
原理图预览：ESP32-S3-WROOM-1-N16R8 主控


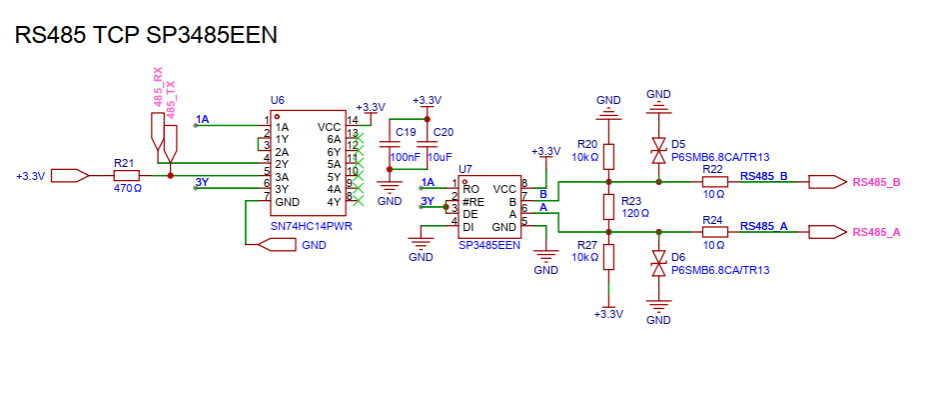
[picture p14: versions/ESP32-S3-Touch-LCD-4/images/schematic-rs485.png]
原理图预览：RS485（SP3485EEN）


完整 PDF：

- [完整原理图（PDF）](./docs/SCH_Esp32s3_3.95in_RS485[模组]_R2_2025-02-05.pdf)

## 快速开始

1. 准备：ESP32-S3-Touch-LCD-4、可用的 USB 数据线（需支持数据传输，不仅充电）、电脑（Windows / Linux / macOS）。
2. 用 USB 连接电脑与面板的 USB 口；电源指示灯应亮起。
3. **验证显示（推荐）**：直接烧录仓库内预编译固件，见下方 [预编译固件](#预编译固件)。
   - Windows 可用乐鑫官方图形工具 **[Flash 下载工具](https://www.espressif.com/zh-hans/support/download/other-tools)**（Flash Download Tools）烧录。
   - 使用说明见：[Flash 下载工具用户指南 · ESP32-S3](https://docs.espressif.com/projects/esp-test-tools/zh_CN/latest/esp32s3/production_stage/tools/flash_download_tool.html)
4. **二次开发**：使用 ESP-IDF 编译 [示例工程](#示例工程)（自动下载依赖串口 DTR/RTS，详见原理图）。

详细硬件说明见：

- [使用指南（PDF）](./docs/ESP32-S3-Touch-LCD-4_使用指南2025.3.14.pdf)

乐鑫官方工具与入门：

- [Flash 下载工具（Windows）](https://www.espressif.com/zh-hans/support/download/other-tools)
- [ESP-IDF 快速入门 · ESP32-S3（中文）](https://docs.espressif.com/projects/esp-idf/zh_CN/latest/esp32s3/get-started/)
- [ESP-IDF Get Started · ESP32-S3（English）](https://docs.espressif.com/projects/esp-idf/en/latest/esp32s3/get-started/)

## 示例工程

触摸走乐鑫 `i2c_master` + `esp_lcd_touch_ft5x06`，已去掉旧版 `driver/i2c.h` / `i2c_driver_install`。屏为 RGB ST7701，480×480。

| 说明 | 路径 |
| ---- | ---- |
| ESP-IDF 5 · LVGL 8 通用 Demo | [`examples/s3-idf5_st7701-rgb_lvgl8-common-demo/`](./examples/s3-idf5_st7701-rgb_lvgl8-common-demo/) |
| ESP-IDF 5 · LVGL 9 通用 Demo | [`examples/s3-idf5_st7701-rgb_lvgl9-common-demo/`](./examples/s3-idf5_st7701-rgb_lvgl9-common-demo/) |
| ESP-IDF 5 · 3.95 寸盒体工程（rev2） | [`examples/ESP32S3_3.95In_Box_rev2/`](./examples/ESP32S3_3.95In_Box_rev2/) |
| ESP-IDF 5 · LVGL 8 游戏 Demo | [`examples/esp32s3_st7701_lvgl-game/`](./examples/esp32s3_st7701_lvgl-game/) |
| ESP-IDF 5 · LVGL 9 Lottie 播放 | [`examples/esp32s3-idf5_st7701-rgb_lvgl9-lottie-player/`](./examples/esp32s3-idf5_st7701-rgb_lvgl9-lottie-player/) |
| ESP-IDF 6 · LVGL 8 通用 Demo | [`examples/esp32s3-idf6_st7701-rgb_lvgl8-common-demo/`](./examples/esp32s3-idf6_st7701-rgb_lvgl8-common-demo/) |
| ESP-IDF 6 · LVGL 9 通用 Demo | [`examples/esp32s3-idf6_st7701-rgb_lvgl9-common-demo/`](./examples/esp32s3-idf6_st7701-rgb_lvgl9-common-demo/) |

在已安装对应版本 ESP-IDF 的环境下（IDF 5 工程建议 ≥5.5；IDF 6 工程用 IDF 6）：

```bash
cd examples/s3-idf5_st7701-rgb_lvgl8-common-demo
idf.py set-target esp32s3
idf.py build
idf.py -p <串口> flash monitor
```

组件依赖由各工程 `main/idf_component.yml` 管理，首次编译会自动拉取。

## 预编译固件

| 文件 | 烧录地址 | 说明 |
| ---- | --- | ---- |
| [`firmware/esp32-s3-touch-lcd-4.bin`](./firmware/esp32-s3-touch-lcd-4.bin) | **`0x0`** | 合并烧录镜像（bootloader + 分区表 + 应用），出厂演示固件 |

Flash 参数与工程配置一致：芯片 **ESP32-S3**，Flash **16 MB**，**DIO**，**80 MHz**。合并包从地址 **`0x0`** 整包写入。

### 方式一：Flash 下载工具（Windows，推荐上手）

1. 下载并打开乐鑫 **[Flash 下载工具](https://www.espressif.com/zh-hans/support/download/other-tools)**。
2. `ChipType` 选 **ESP32-S3**，`WorkMode` 选 Develop，`LoadMode` 选 UART。
3. 勾选一行，固件选 [`firmware/esp32-s3-touch-lcd-4.bin`](./firmware/esp32-s3-touch-lcd-4.bin)，地址填 **`0x0`**（不要填成应用分区的 `0x10000`）。
4. SPI SPEED / SPI MODE / FLASH SIZE 按上表选择（80 MHz、DIO、16 MB）。
5. 选择正确 COM 口，点 **START** 烧录。

详细界面说明见：[Flash 下载工具用户指南 · ESP32-S3](https://docs.espressif.com/projects/esp-test-tools/zh_CN/latest/esp32s3/production_stage/tools/flash_download_tool.html)

### 方式二：esptool（命令行）

将 `<串口>` 换成实际端口（如 `/dev/ttyUSB0`、`COM3`）；地址为 **`0x0`**：

```bash
esptool.py --chip esp32s3 -p <串口> write_flash 0x0 firmware/esp32-s3-touch-lcd-4.bin
```

## 仓库结构

```text
esp32-s3-touch-lcd-4/                                # 仓库根（导航见 ../../README.md）
└── versions/
    └── ESP32-S3-Touch-LCD-4/                        # 本型号完整资料
        ├── README.md
        ├── README_EN.md
        ├── images/
        ├── docs/
        ├── firmware/
        └── examples/
```

## 相关资料

### 本产品资料

- [使用指南（PDF）](./docs/ESP32-S3-Touch-LCD-4_使用指南2025.3.14.pdf)
- [完整原理图（PDF）](./docs/SCH_Esp32s3_3.95in_RS485[模组]_R2_2025-02-05.pdf)
- [屏模组规格书 YDP395BT009-V1（PDF）](./docs/YDP395BT009-V1.pdf)
- [总成图 CAD（YDP395BT009-V1）](./docs/YDP395BT009-V1.dwg)
- [驱动 IC ST7701S Datasheet（PDF）](./docs/ST7701S_SPEC_V1.3.pdf)
- [触摸 IC FT6336U Datasheet（PDF）](./docs/FT6336U_DataSheet_V1.1.pdf)
- [初始化序列（文本）](./docs/BOE3.95_480x480_ST7701S_init.txt)
- [示例工程](#示例工程)
- [预编译固件 esp32-s3-touch-lcd-4.bin](./firmware/esp32-s3-touch-lcd-4.bin)

### 系列通用外壳 CAD

86 型外壳（2 层 / 4 层）全型号通用，文件在仓库根 `docs/`。

- [4 层：`0302(1).dwg`](../../docs/86-enclosure-4-layer/0302(1).dwg)
- [4 层：`WSD4寸-2d-1116.dwg`](../../docs/86-enclosure-4-layer/WSD4%E5%AF%B8-2d-1116.dwg)
- [2 层：`3.95-01 PCB.dwg`](../../docs/86-enclosure-2-layer/3.95-01%20PCB.dwg)
- [2 层：`增加开口结构外壳20250102.dwg`](../../docs/86-enclosure-2-layer/%E5%A2%9E%E5%8A%A0%E5%BC%80%E5%8F%A3%E7%BB%93%E6%9E%84%E5%A4%96%E5%A3%B320250102.dwg)
- [2 层：`装配0718(1).DWG`](../../docs/86-enclosure-2-layer/%E8%A3%85%E9%85%8D0718(1).DWG)

### 芯片资料（乐鑫官方）

- [ESP32-S3 系列产品页（中文）](https://www.espressif.com/zh-hans/products/socs/esp32-s3)
- [ESP32-S3 系列产品页（英文）](https://www.espressif.com/en/products/socs/esp32-s3)
- [ESP-IDF 编程指南 · ESP32-S3（中文）](https://docs.espressif.com/projects/esp-idf/zh_CN/latest/esp32s3/index.html)
- [ESP-IDF Programming Guide · ESP32-S3（English）](https://docs.espressif.com/projects/esp-idf/en/latest/esp32s3/index.html)

## 购买链接

<p align="center">
  
  &nbsp;&nbsp;
  
</p>

**国内（淘宝）**

- 店铺：[鱼鹰光电工厂店](https://shop110742373.taobao.com/)

**海外（AliExpress）**

- 店铺：[OSPTEK Official Store](https://www.aliexpress.com/store/1105701619)

---

## 技术支持

如有技术问题或合作需求，欢迎通过以下方式联系我们：

- 技术支持 / 产品咨询：<luyu@osptek.com>
- QQ 技术交流群：**985881096**
- 公司官网：<https://osptek.com/>
- 有任何问题，都可以在本仓库 Issues 中提问

---

<p align="center"><sub>© 2026 OSPTEK 鱼鹰光电 · 本仓库资料采用 CC BY 4.0 许可</sub></p>

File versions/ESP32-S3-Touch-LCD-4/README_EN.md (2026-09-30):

<p align="left">OSPTEK</p>

<h1 align="center">OSPTEK ESP32-S3-Touch-LCD-4 Touch Panel</h1>

<p align="center"><b>86-Type Panel · Touch UI · One RS485 Port</b></p>

<p align="center">English | <a href="./README.md">简体中文</a> · <a href="../../README_EN.md">Family index</a></p>

<p align="center">
  
  
  
  
  
</p>

<p align="center">OSPTEK ESP32-S3-Touch-LCD-4 product image</p>

## Contents

- [Overview](#overview)
- [Other SKUs in this series](#other-skus-in-this-series)
- [Features](#features)
- [Applications](#applications)
- [Specifications](#specifications)
- [Display](#display)
- [Hardware Resources](#hardware-resources)
- [Quick Start](#quick-start)
- [Examples](#examples)
- [Prebuilt Firmware](#prebuilt-firmware)
- [Repository Structure](#repository-structure)
- [Documentation](#documentation)
- [Where to Buy](#where-to-buy)
- [Support](#support)

---

## Overview

OSPTEK **ESP32-S3-Touch-LCD-4** is a **4-inch touch panel** based on an ESP32-S3 module (2.4 GHz Wi-Fi + Bluetooth LE 5), with **16 MB Flash** and **8 MB PSRAM**, and an onboard **YDP395BT009-V1** (~3.95") **480×480** RGB capacitive touch display (driver **ST7701S**).

The main board is **ESP32-TPCB4**, with module **ESP32-S3-WROOM-1-N16R8**. It includes one **RS485** port, USB Type-C (power / flash / charge), an I²C sensor header, and a buzzer—suited as a finished product for smart control panels and interactive HMI.

## Features

- **4" square touch display**: YDP395BT009-V1, 480×480, ST7701S + capacitive touch, ideal for 86-type panel UIs
- **ESP32-S3 MCU**: Wi-Fi + BLE 5, 16 MB Flash + 8 MB PSRAM
- **Industrial bus**: onboard RS485 (SP3485EEN + auto direction control) for field devices
- **Flexible power**: USB Type-C provides 5 V; terminal block supports **12–24 VDC** wide-range input (via DCDC)
- **Battery management**: IP5306 charge/discharge for battery-powered use
- **Easy debug**: CH340K USB-UART with auto-download (DTR/RTS control EN / IO0)
- **Expansion**: I²C sensor port, LCD FPC connector, onboard buzzer, and more

## Applications

- Smart home central control / 86-type interactive panels
- Home gateway and local HMI
- Industrial control and device status displays
- Smart lighting and building panels

## Specifications

### MCU & Memory

| Item | Specification |
| ---- | --- |
| Product model | ESP32-S3-Touch-LCD-4 |
| Main board | ESP32-TPCB4 |
| Module | ESP32-S3-WROOM-1-N16R8 |
| Flash | 16 MB |
| PSRAM | 8 MB |
| Wireless | 2.4 GHz Wi-Fi, Bluetooth LE 5 |

### Display & Touch

Summary below; full module parameters, driver, and touch details are in [Display](#display).

| Item | Specification |
| ---- | --- |
| Panel module | YDP395BT009-V1 (~3.95") |
| Resolution | 480×480 |
| Driver IC | ST7701S |
| Display interface | RGB 18-bit |
| Touch | Capacitive (FT6336U, I²C) |
| Brightness | 350 cd/m² typ. |

### Interfaces & Power

| Item | Specification |
| ---- | --- |
| USB | Type-C (power, flash, charge) |
| USB-UART | CH340K (up to ~2 Mbaud) |
| RS485 | SP3485EEN, half-duplex; SN74HC14PWR auto direction |
| Terminal | 5.08 mm 4-pin |
| Sensor | I²C |
| Audio cue | Onboard buzzer |
| USB power | 5 V |
| Terminal power | 12–24 VDC (onboard DCDC to 5 V) |
| Power management | IP5306 (~2.1 A charge / 2.4 A discharge) |

## Display

This panel uses OSPTEK TFT module **YDP395BT009-V1** with driver IC **ST7701S**, connected via the board LCD FPC. Touch is capacitive (I²C, FT6336U).

### Module Specifications (YDP395BT009-V1)

| Item | Specification |
| ---- | --- |
| Module model | YDP395BT009-V1 |
| Size | 3.95" (diagonal) |
| Display mode | Normally black |
| Resolution | 480 (H) RGB × 480 (V) |
| Dot pitch | 153 μm × 153 μm |
| Active area | 71.86 × 70.18 mm |
| Module outline | 83.85 × 83.85 × 3.27 mm |
| Color arrangement | RGB vertical stripe |
| Interface | RGB 18-bit (HSYNC / VSYNC / DE / DCLK); driver init via 3-wire SPI (SDA / SCL / CS) |
| Driver IC | ST7701S |
| Brightness | 350 cd/m² typ. (min. ~300) |
| Viewing angle | All view (typ. ~80°) |
| Contrast ratio | ~1000:1 typ. |
| Backlight | 8 white LEDs (typ. ~12 V / 40 mA) |
| Operating temp. | −20 ℃ ~ +70 ℃ |
| Storage temp. | −30 ℃ ~ +80 ℃ |

Touch signals such as `TP_SCL` / `TP_SDA` / `TP_INT` / `TP_RESET` are brought out on the same FPC; typical touch supply is 2.8–3.3 V.

### Display Documents

- [Panel datasheet YDP395BT009-V1 (PDF)](./docs/YDP395BT009-V1.pdf)
- [Assembly CAD (YDP395BT009-V1)](./docs/YDP395BT009-V1.dwg)
- [Driver IC ST7701S datasheet (PDF)](./docs/ST7701S_SPEC_V1.3.pdf)
- [Touch IC FT6336U datasheet (PDF)](./docs/FT6336U_DataSheet_V1.1.pdf)
- [Init sequence (text)](./docs/BOE3.95_480x480_ST7701S_init.txt)

## Hardware Resources

### Onboard Overview

| Resource | Description |
| --- | --- |
| ESP32-S3-WROOM-1-N16R8 | Wi-Fi + BLE MCU module |
| Power LED | Red when powered |
| RS485 transceiver | SP3485EEN + auto direction circuit |
| USB bridge | CH340K |
| DCDC | SGM6132, wide-range input to 5 V |
| LCD connector | 0.5 mm-pitch FPC to the LCD |
| Buzzer | Onboard audio cue |

### Board Layout

<p align="center">ESP32-S3-Touch-LCD-4 board connectors and component callouts</p>

More detailed text descriptions are in the [user guide](./docs/ESP32-S3-Touch-LCD-4_使用指南2025.3.14.pdf) (Chinese PDF).

### Schematic

Preview (excerpts):

<p align="center">Schematic preview: ESP32-S3-WROOM-1-N16R8 MCU</p>

<p align="center">Schematic preview: RS485 (SP3485EEN)</p>

Full PDF:

- [Full schematic (PDF)](./docs/SCH_Esp32s3_3.95in_RS485[模组]_R2_2025-02-05.pdf)

## Quick Start

1. Prepare: ESP32-S3-Touch-LCD-4, a data-capable USB cable (not charge-only), and a PC (Windows / Linux / macOS).
2. Connect USB between the PC and the panel USB port; the power LED should light.
3. **Verify the display (recommended)**: flash the prebuilt firmware in this repo—see [Prebuilt Firmware](#prebuilt-firmware).
   - On Windows, use Espressif’s graphical **[Flash Download Tools](https://www.espressif.com/en/support/download/other-tools)**.
   - Guide: [Flash Download Tool User Guide · ESP32-S3](https://docs.espressif.com/projects/esp-test-tools/en/latest/esp32s3/production_stage/tools/flash_download_tool.html)
4. **Application development**: build the [example](#examples) with ESP-IDF (auto-download via UART DTR/RTS; see schematic).

Hardware details:

- [User guide (PDF, Chinese)](./docs/ESP32-S3-Touch-LCD-4_使用指南2025.3.14.pdf)

Espressif tools & getting started:

- [Flash Download Tools (Windows)](https://www.espressif.com/en/support/download/other-tools)
- [ESP-IDF Get Started · ESP32-S3](https://docs.espressif.com/projects/esp-idf/en/latest/esp32s3/get-started/)
- [ESP-IDF 快速入门 · ESP32-S3（中文）](https://docs.espressif.com/projects/esp-idf/zh_CN/latest/esp32s3/get-started/)

## Examples

Touch uses Espressif `i2c_master` + `esp_lcd_touch_ft5x06` (legacy `driver/i2c.h` / `i2c_driver_install` removed). Panel: RGB ST7701, 480×480.

| Description | Path |
| --- | ---- |
| ESP-IDF 5 · LVGL 8 common demo | [`examples/s3-idf5_st7701-rgb_lvgl8-common-demo/`](./examples/s3-idf5_st7701-rgb_lvgl8-common-demo/) |
| ESP-IDF 5 · LVGL 9 common demo | [`examples/s3-idf5_st7701-rgb_lvgl9-common-demo/`](./examples/s3-idf5_st7701-rgb_lvgl9-common-demo/) |
| ESP-IDF 5 · 3.95" box project (rev2) | [`examples/ESP32S3_3.95In_Box_rev2/`](./examples/ESP32S3_3.95In_Box_rev2/) |
| ESP-IDF 5 · LVGL 8 game demo | [`examples/esp32s3_st7701_lvgl-game/`](./examples/esp32s3_st7701_lvgl-game/) |
| ESP-IDF 5 · LVGL 9 Lottie player | [`examples/esp32s3-idf5_st7701-rgb_lvgl9-lottie-player/`](./examples/esp32s3-idf5_st7701-rgb_lvgl9-lottie-player/) |
| ESP-IDF 6 · LVGL 8 common demo | [`examples/esp32s3-idf6_st7701-rgb_lvgl8-common-demo/`](./examples/esp32s3-idf6_st7701-rgb_lvgl8-common-demo/) |
| ESP-IDF 6 · LVGL 9 common demo | [`examples/esp32s3-idf6_st7701-rgb_lvgl9-common-demo/`](./examples/esp32s3-idf6_st7701-rgb_lvgl9-common-demo/) |

With the matching ESP-IDF installed (IDF 5 projects: ≥5.5; IDF 6 projects: IDF 6):

```bash
cd examples/s3-idf5_st7701-rgb_lvgl8-common-demo
idf.py set-target esp32s3
idf.py build
idf.py -p <PORT> flash monitor
```

Component dependencies are managed by each project's `main/idf_component.yml` and are fetched on the first build.

## Prebuilt Firmware

| File | Flash address | Description |
| ---- | --- | --- |
| [`firmware/esp32-s3-touch-lcd-4.bin`](./firmware/esp32-s3-touch-lcd-4.bin) | **`0x0`** | Merged image (bootloader + partition table + app), factory demo firmware |

Flash settings match the project: chip **ESP32-S3**, Flash **16 MB**, **DIO**, **80 MHz**. Write the merged package from address **`0x0`**.

### Option 1: Flash Download Tools (Windows, easiest)

1. Download and open Espressif **[Flash Download Tools](https://www.espressif.com/en/support/download/other-tools)**.
2. Set `ChipType` to **ESP32-S3**, `WorkMode` to Develop, `LoadMode` to UART.
3. Enable one row, select [`firmware/esp32-s3-touch-lcd-4.bin`](./firmware/esp32-s3-touch-lcd-4.bin), address **`0x0`** (do not use app-partition `0x10000`).
4. Set SPI SPEED / SPI MODE / FLASH SIZE as above (80 MHz, DIO, 16 MB).
5. Select the correct COM port and click **START**.

UI details: [Flash Download Tool User Guide · ESP32-S3](https://docs.espressif.com/projects/esp-test-tools/en/latest/esp32s3/production_stage/tools/flash_download_tool.html)

### Option 2: esptool (CLI)

Replace `<PORT>` with your serial port (e.g. `/dev/ttyUSB0`, `COM3`); address is **`0x0`**:

```bash
esptool.py --chip esp32s3 -p <PORT> write_flash 0x0 firmware/esp32-s3-touch-lcd-4.bin
```

## Repository layout

```text
esp32-s3-touch-lcd-4/                                # repo root (nav: ../../README_EN.md)
└── versions/
    └── ESP32-S3-Touch-LCD-4/                        # full materials for this SKU
        ├── README.md
        ├── README_EN.md
        ├── images/
        ├── docs/
        ├── firmware/
        └── examples/
```

## Documentation

### Product Documents

- [User guide (PDF, Chinese)](./docs/ESP32-S3-Touch-LCD-4_使用指南2025.3.14.pdf)
- [Full schematic (PDF)](./docs/SCH_Esp32s3_3.95in_RS485[模组]_R2_2025-02-05.pdf)
- [Panel datasheet YDP395BT009-V1 (PDF)](./docs/YDP395BT009-V1.pdf)
- [Assembly CAD (YDP395BT009-V1)](./docs/YDP395BT009-V1.dwg)
- [Driver IC ST7701S datasheet (PDF)](./docs/ST7701S_SPEC_V1.3.pdf)
- [Touch IC FT6336U datasheet (PDF)](./docs/FT6336U_DataSheet_V1.1.pdf)
- [Init sequence (text)](./docs/BOE3.95_480x480_ST7701S_init.txt)
- [Examples](#examples)
- [Prebuilt firmware esp32-s3-touch-lcd-4.bin](./firmware/esp32-s3-touch-lcd-4.bin)

### Shared enclosure CAD

The 86-type enclosure (2-layer / 4-layer) is shared by every SKU. Files live in the repo-root `docs/` folder.

- [4-layer: `0302(1).dwg`](../../docs/86-enclosure-4-layer/0302(1).dwg)
- [4-layer: `WSD4寸-2d-1116.dwg`](../../docs/86-enclosure-4-layer/WSD4%E5%AF%B8-2d-1116.dwg)
- [2-layer: `3.95-01 PCB.dwg`](../../docs/86-enclosure-2-layer/3.95-01%20PCB.dwg)
- [2-layer: `增加开口结构外壳20250102.dwg`](../../docs/86-enclosure-2-layer/%E5%A2%9E%E5%8A%A0%E5%BC%80%E5%8F%A3%E7%BB%93%E6%9E%84%E5%A4%96%E5%A3%B320250102.dwg)
- [2-layer: `装配0718(1).DWG`](../../docs/86-enclosure-2-layer/%E8%A3%85%E9%85%8D0718(1).DWG)

### Chip Documents (Espressif)

- [ESP32-S3 product page](https://www.espressif.com/en/products/socs/esp32-s3)
- [ESP32-S3 系列产品页（中文）](https://www.espressif.com/zh-hans/products/socs/esp32-s3)
- [ESP-IDF Programming Guide · ESP32-S3](https://docs.espressif.com/projects/esp-idf/en/latest/esp32s3/index.html)
- [ESP-IDF 编程指南 · ESP32-S3（中文）](https://docs.espressif.com/projects/esp-idf/zh_CN/latest/esp32s3/index.html)

## Where to Buy

<p align="center">
  
  &nbsp;&nbsp;
  
</p>

**International (AliExpress)**

- Store: [OSPTEK Official Store](https://www.aliexpress.com/store/1105701619)

**China (Taobao)**

- Store: [鱼鹰光电工厂店](https://shop110742373.taobao.com/)

---

## Support

For technical questions or business inquiries:

- Technical support / product inquiry: <luyu@osptek.com>
- QQ technical group: **985881096**
- Website: <https://osptek.com/>
- Feel free to open an Issue in this repository if you have any questions

---

<p align="center"><sub>© 2026 OSPTEK · Materials in this repository are licensed under CC BY 4.0</sub></p>

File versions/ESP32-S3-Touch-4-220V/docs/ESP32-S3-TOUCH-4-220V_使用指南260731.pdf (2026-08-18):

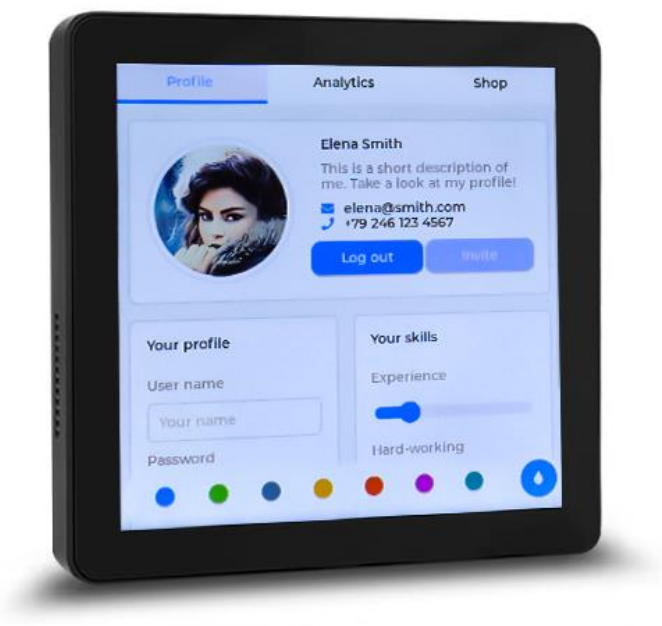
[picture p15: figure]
ESP32-S3-313LCD

# 鱼鹰光电 | 咨询热线：0755-26810170 | 网址：www.yuyinglcd.com

# 4 英寸智能触摸开发板

# ESP32-S3-Touch-4-220V | 4 英寸智能触摸开发板

# 1.产品简介

# ESP32-S3-Touch-4-220V 是一款集成 4 英寸触摸显示、ESP32-S3 高性能 WiFi/BLE 控制模块、220V 交流输入

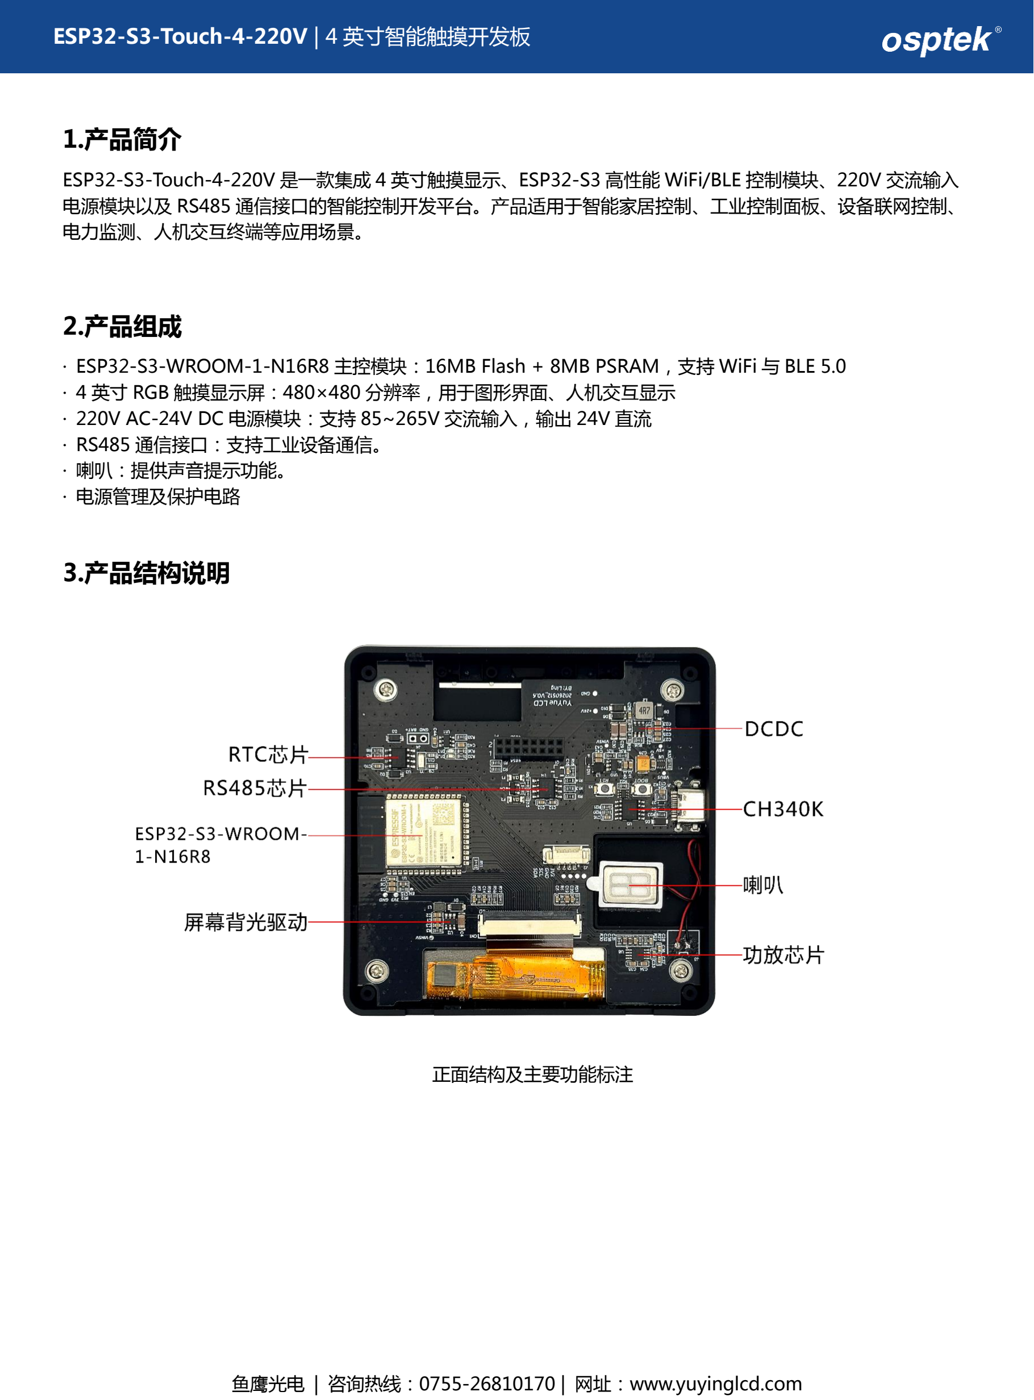
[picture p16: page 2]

# 电源模块以及 RS485 通信接口的智能控制开发平台。产品适用于智能家居控制、工业控制面板、设备联网控制、 电力监测、人机交互终端等应用场景。

# 2.产品组成

# - ESP32-S3-WROOM-1-N16R8 主控模块：16MB Flash + 8MB PSRAM，支持 WiFi 与 BLE 5.0 - 4 英寸 RGB 触摸显示屏：480×480 分辨率，用于图形界面、人机交互显示 - 220V AC-24V DC 电源模块：支持 85~265V 交流输入，输出 24V 直流 - RS485 通信接口：支持工业设备通信。

# 3.产品结构说明

# 正面结构及主要功能标注

# ESP32-S3-Touch-4-220V | 4 英寸智能触摸开发板

# - 喇叭：提供声音提示功能。 - 电源管理及保护电路

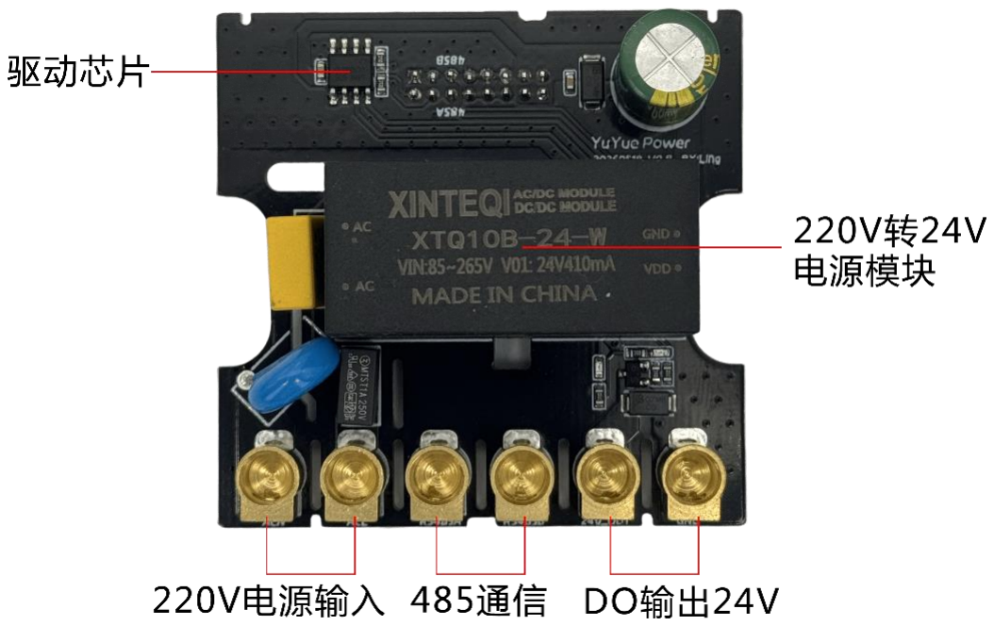
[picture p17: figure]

# 背面 220V 电源模块及接口

# 4.硬件功能说明

模块 | 功能说明
ESP32-S3 主控 | 高性能 WiFi+BLE MCU，支持 AIoT 应用开发
4 寸 LCD 触摸屏 | 480×480 RGB 显示，支持触控交互
220V 电源模块 | AC85~265V 输入，24V DC 输出
RS485 接口 | 工业现场通信接口
USB Type-C | 程序下载、调试及供电
喇叭 | 声音提醒

# 5.接口定义

# 底部端子接口定义：

# （1）AC 输入：220V 交流电源输入 （2）RS485A / RS485B：485 通信接口 （3）24V 输出：直流电源输出 （4）GND：电源地

# ESP32-S3-Touch-LCD-4-220V | 4 英寸智能触摸开发板

·

# 6. 电源说明及安全注意事项

# - 设备支持 AC85~265V 宽电压输入。 - 220V 交流输入属于高压区域，禁止带电操作。

# - 首次使用前请确认接线正确，避免短路损坏设备。 - 建议由具备电气操作经验人员进行安装调试。

# 7. 开发使用说明

# （1）使用 USB Type-C 连接电脑进行程序下载和调试。 （2）使用 ESP-IDF 或 Arduino 开发环境进行软件开发。 （3）根据项目需求开发 LCD 界面、触摸交互及通信功能。

# 8. 应用场景

# - 智能家居控制终端 - 工业设备控制面板 - 智能电力控制系统

# - IoT 物联网网关

# - 自动化设备人机界面

# 9. 技术支持

# 深圳市鱼鹰光电科技有限公司

# 官方网站：www.yuyinglcd.com 咨询热线：0755-26810170

10.附件

# 原理图

# ESP32-S3-Touch-LCD-4-220V | 4 英寸智能触摸开发板

1

2

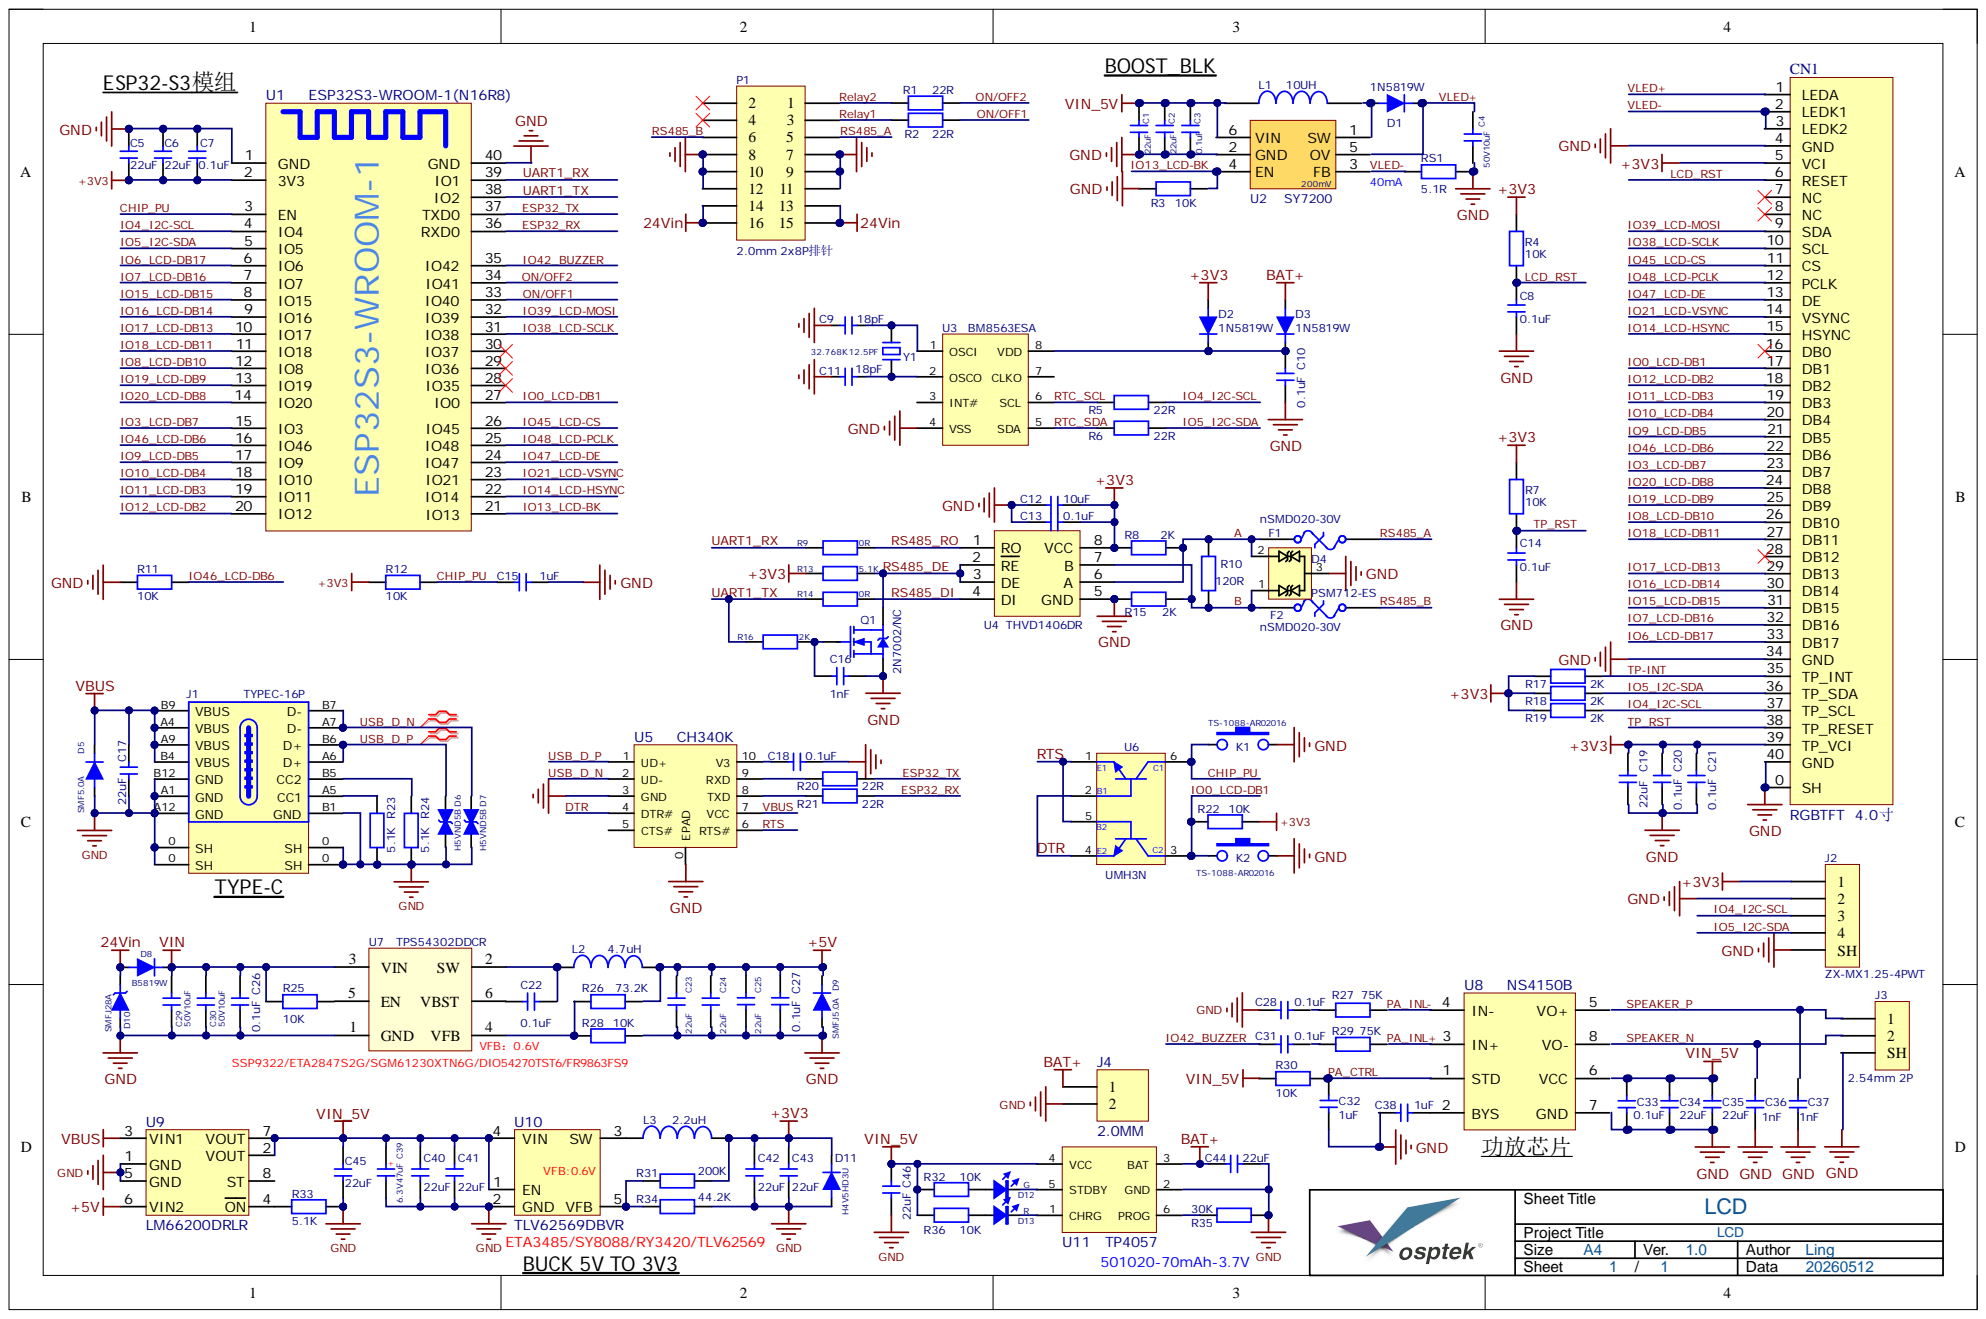
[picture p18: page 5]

1

2

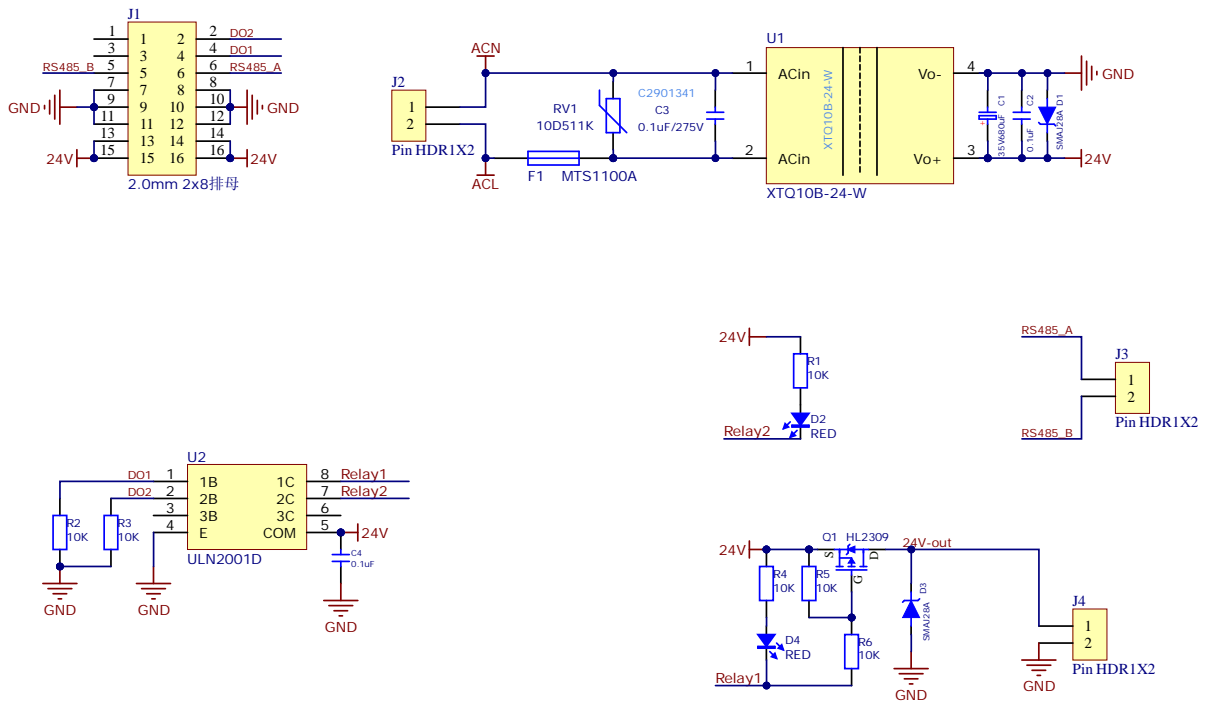
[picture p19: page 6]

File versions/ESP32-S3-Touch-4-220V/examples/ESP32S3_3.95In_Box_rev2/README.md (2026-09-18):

> 80M PSRAM

...
CONFIG_COMPILER_OPTIMIZATION_PERF=y
CONFIG_ESP_DEFAULT_CPU_FREQ_MHZ_240=y
CONFIG_ESP32S3_DATA_CACHE_LINE_64B=y
CONFIG_ESPTOOLPY_FLASHMODE_QIO=y
CONFIG_ESPTOOLPY_FLASHFREQ_80M=y
CONFIG_ESPTOOLPY_FLASHSIZE_16MB=y

# 启用 PSRAM 80M
CONFIG_SPIRAM=y
CONFIG_SPIRAM_MODE_OCT=y
CONFIG_SPIRAM_FETCH_INSTRUCTIONS=y
CONFIG_SPIRAM_RODATA=y
CONFIG_SPIRAM_SPEED_80M=y

# 使用partitions.csv
CONFIG_PARTITION_TABLE_CUSTOM=y
CONFIG_PARTITION_TABLE_CUSTOM_FILENAME="partitions.csv"
CONFIG_PARTITION_TABLE_FILENAME="partitions.csv"

# 开启防撕裂
CONFIG_EXAMPLE_LVGL_PORT_AVOID_TEAR_ENABLE=y
...

> 120M PSRAM

...
# 启用 PSRAM 120M
CONFIG_SPIRAM=y
CONFIG_SPIRAM_MODE_OCT=y
CONFIG_IDF_EXPERIMENTAL_FEATURES=y
CONFIG_SPIRAM_SPEED_120M=y
CONFIG_SPIRAM_FETCH_INSTRUCTIONS=y
CONFIG_SPIRAM_RODATA=y

# 启用以下配置可以帮助在以下情况下提高 PCLK 频率：
# 帧缓冲区从 PSRAM 中分配，并由 EDMA 提取
CONFIG_FREERTOS_HZ=1000
CONFIG_ESP_DEFAULT_CPU_FREQ_MHZ_240=y
CONFIG_ESPTOOLPY_FLASHMODE_QIO=y
CONFIG_ESPTOOLPY_FLASHFREQ_120M=y
CONFIG_ESPTOOLPY_FLASHSIZE_16MB=y
CONFIG_ESP32S3_DATA_CACHE_LINE_32B=y
CONFIG_COMPILER_OPTIMIZATION_PERF=y

# 使用partitions.csv
CONFIG_PARTITION_TABLE_CUSTOM=y
CONFIG_PARTITION_TABLE_CUSTOM_FILENAME="partitions.csv"
CONFIG_PARTITION_TABLE_FILENAME="partitions.csv"

# 开启防撕裂
CONFIG_EXAMPLE_LVGL_PORT_AVOID_TEAR_ENABLE=y
...

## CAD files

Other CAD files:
docs/86-enclosure-2-layer/装配0718(1).DWG
docs/86-enclosure-4-layer/0302(1).dwg
versions/ESP32-S3-Touch-4-220V/docs/YDP395BT009-V1.dwg
versions/ESP32-S3-Touch-4-Classic/docs/YDP395BT009-V1.dwg
versions/ESP32-S3-Touch-4-Pro/docs/YDP395BT009-V1.dwg
versions/ESP32-S3-Touch-LCD-4/docs/YDP395BT009-V1.dwg
docs/86-enclosure-2-layer/增加开口结构外壳20250102.dwg
docs/86-enclosure-4-layer/WSD4寸-2d-1116.dwg
docs/86-enclosure-2-layer/3.95-01 PCB.dwg

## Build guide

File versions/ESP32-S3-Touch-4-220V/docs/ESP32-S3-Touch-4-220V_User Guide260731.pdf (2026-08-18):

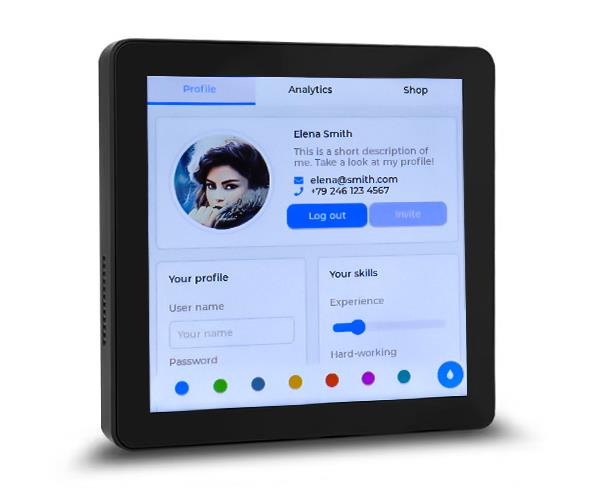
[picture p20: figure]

Osprey Optoelectronics | | | Hotline：0755-26810170 | Website：www.yuyinglcd.com

# ESP32-S3-Touch-4-220V

# 4-inch Touch Display Development Board

## ESP32-S3-Touch-4-220V | 4-inch Touch Display Development Board

## 1. Product Overview

ESP32-S3-Touch-4-220V is an integrated smart touch control development board featuring ESP32-S3 Wi-Fi/BLE

MCU, a 4-inch RGB capacitive touch display, 220V AC power input, 24V DC output and RS485 communication

interface.

## 2. Hardware Configuration

·ESP32-S3-WROOM-1-N16R8 Main Control Module: 16MB Flash + 8MB PSRAM, supports WiFi and BLE 5.0

·4-inch RGB Touch Display: 480×480 resolution, used for graphical interface and human-machine interaction

display
·220V AC to 24V DC Power Supply Module: Supports 85~265V AC input, outputs 24V DC

·RS485 Communication Interface: Supports industrial device communication

·Speaker: Provides audio output/playback functions

·Power Management and Protection Circuitry

## 3. Main Components

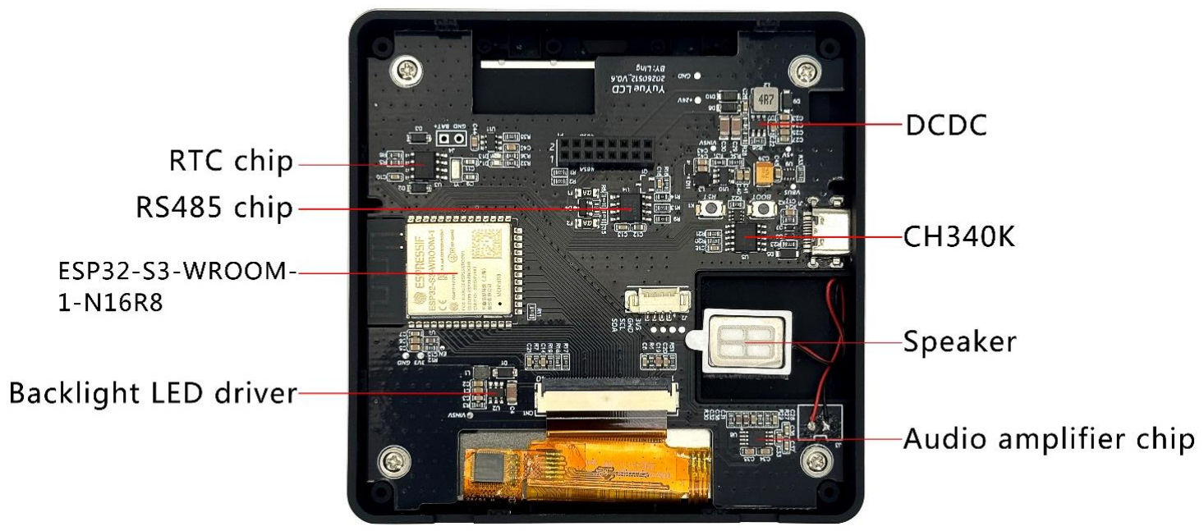
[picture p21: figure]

Front View: Structure and Main Function Callouts

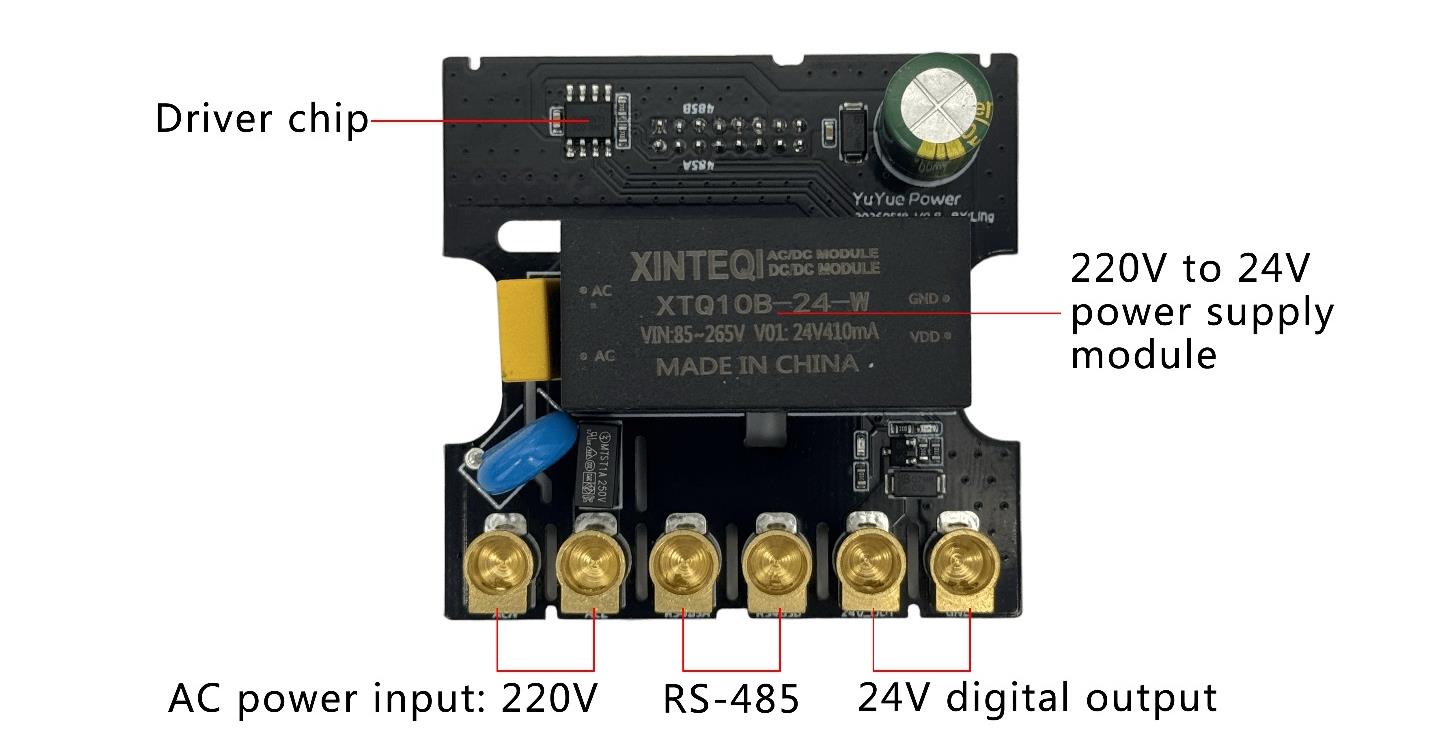
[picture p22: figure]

Rear View: 220V Power Module and Interfaces

## 4. Interface Definition

Module | Function Description
ESP32-S3 Main Controller | High-performance WiFi + BLE MCU, supports AIoT application development
4-inch LCD Touch Screen | 480×480 RGB display, supports touch interaction
220V Power Supply Module | AC85–265V input, 24V DC output
RS485 Interface | Industrial field communication interface
USB Type-C | Program download, debugging, and power supply
Speaker | Audio alert / sound notification

## 5. Interface Definition

Bottom Terminal Interface Definition:

(1) AC Input: 220V AC power input
(2) RS485A / RS485B: RS-485 communication interface
(3) 24V Output: DC power output
(4) GND: Power ground

·

## 6. Power Supply Instructions and Safety Precautions

·The device supports AC85–265V wide-range voltage input.

·The 220V AC input is a high-voltage area. Do not perform any operation while the power is on.

·Before first use, please verify that all wiring is correct to avoid short circuits that may damage the device.

·It is recommended that installation and debugging be carried out by personnel with experience in electrical

operations.

## 7. Development and Usage Instructions

(1) Connect to a computer via USB Type-C for program downloading and debugging.
(2) Use the ESP-IDF or Arduino development environment for software development.
(3) Develop LCD interface, touch interaction, and communication functions according to project requirements.

## 8. Application Scenarios

·Smart home control terminal

·Industrial equipment control panel

·Intelligent power control system

·IoT gateway

·Human-machine interface for automation equipment

## 9. Technical Support

Shenzhen Yuying Optoelectronics Technology Co., Ltd.

Official Website: www.yuyinglcd.com

Hotline: 0755-26810170

## 10. Attachments

Schematic Diagram

IO20 14 | IO19 13 | IO8 12 | IO18 11 | IO17 10 | IO16 9 | IO15 8 | IO7 7 | IO6 6 | IO5 5 | IO4 4 | EN 3



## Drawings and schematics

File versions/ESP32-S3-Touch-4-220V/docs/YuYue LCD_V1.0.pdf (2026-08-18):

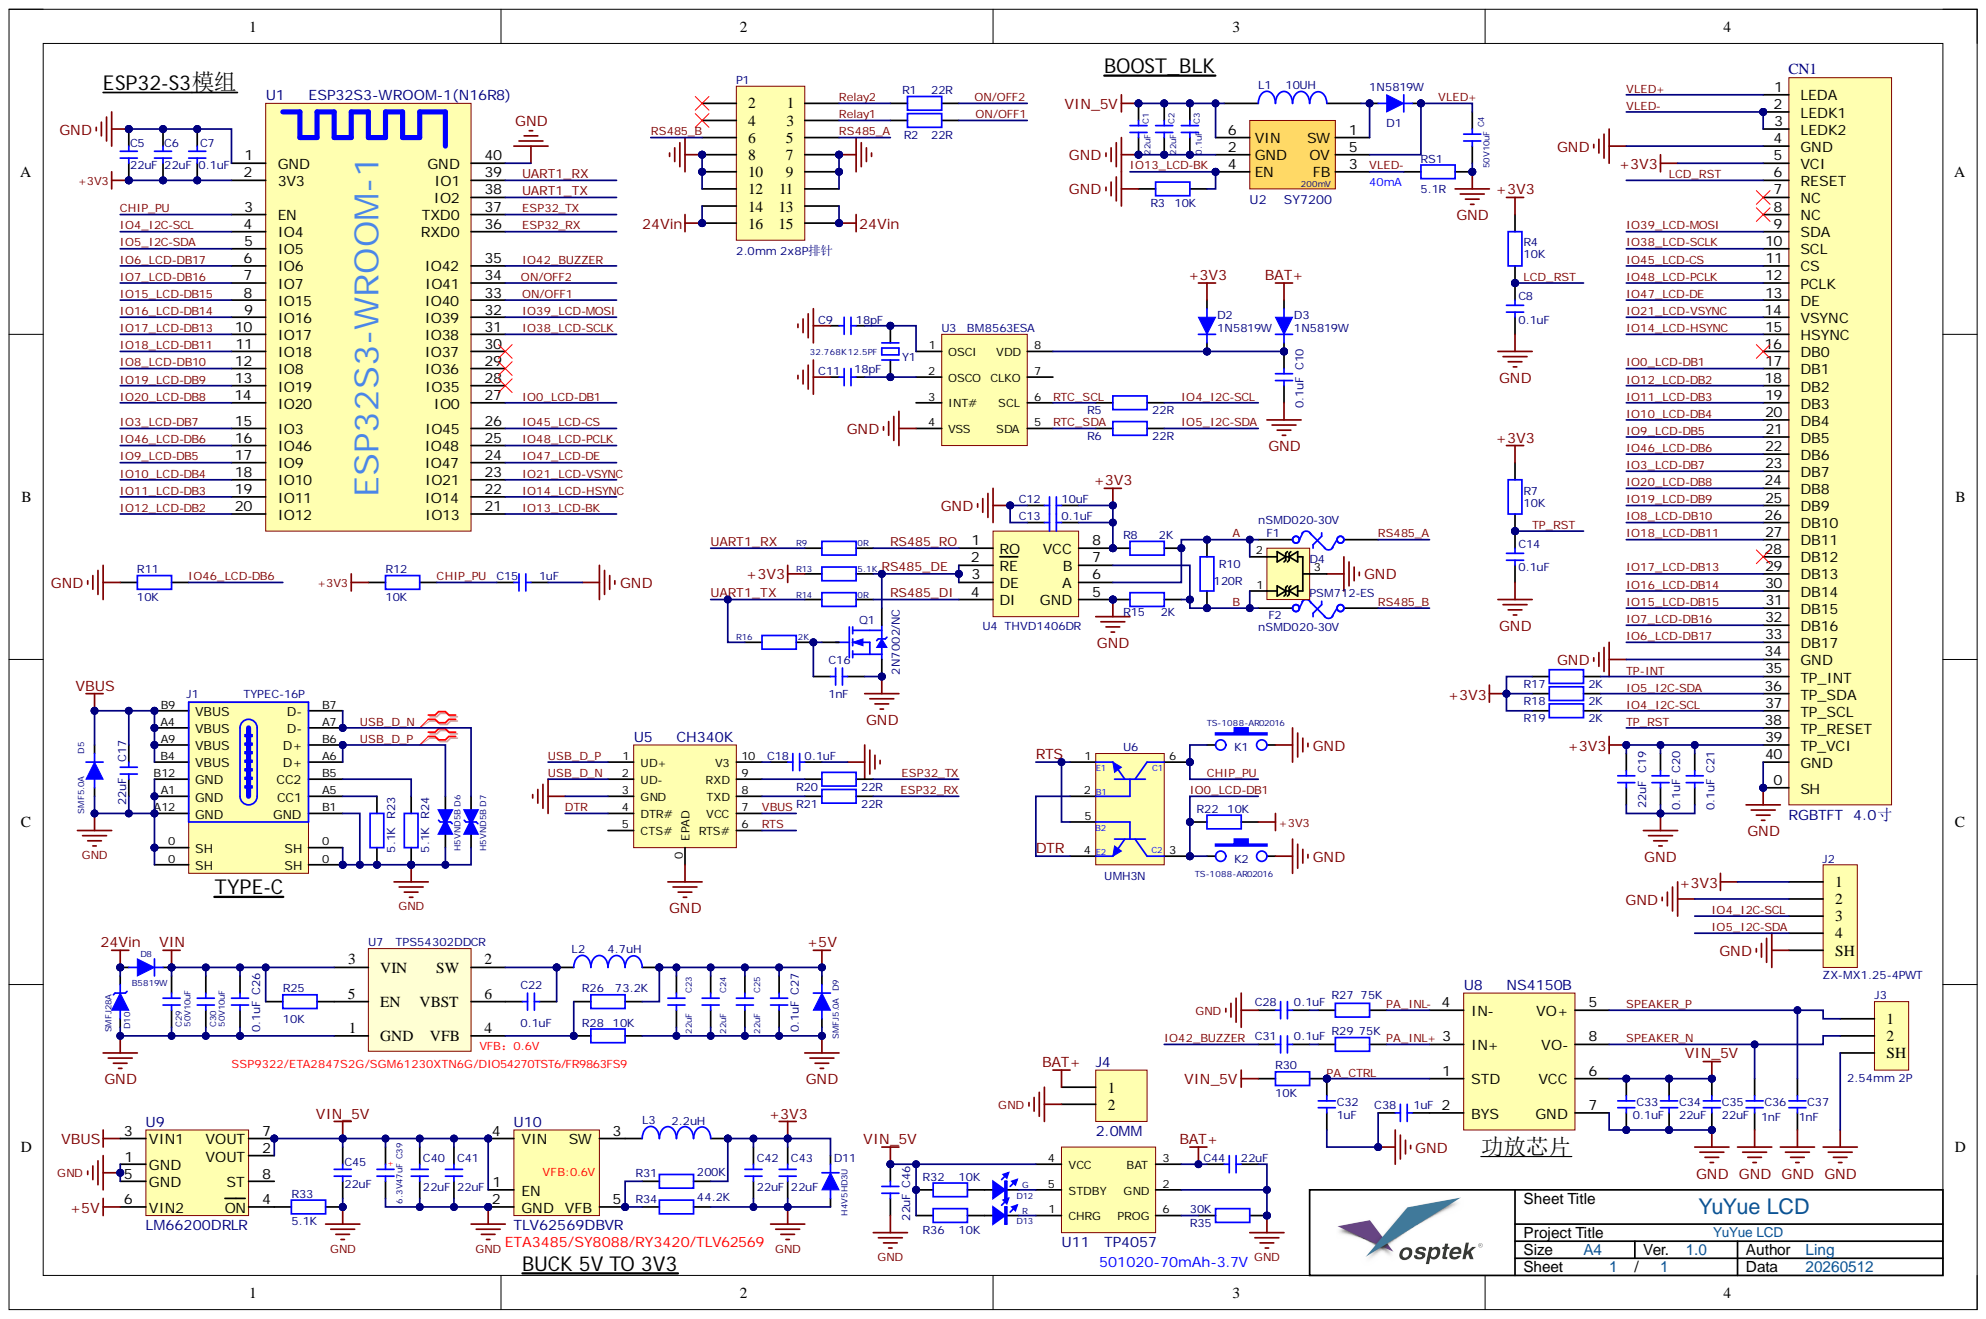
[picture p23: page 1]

Size A4 | Ver. 1.0 | Author Ling
Sheet 1 / 1 | | Data 20260512

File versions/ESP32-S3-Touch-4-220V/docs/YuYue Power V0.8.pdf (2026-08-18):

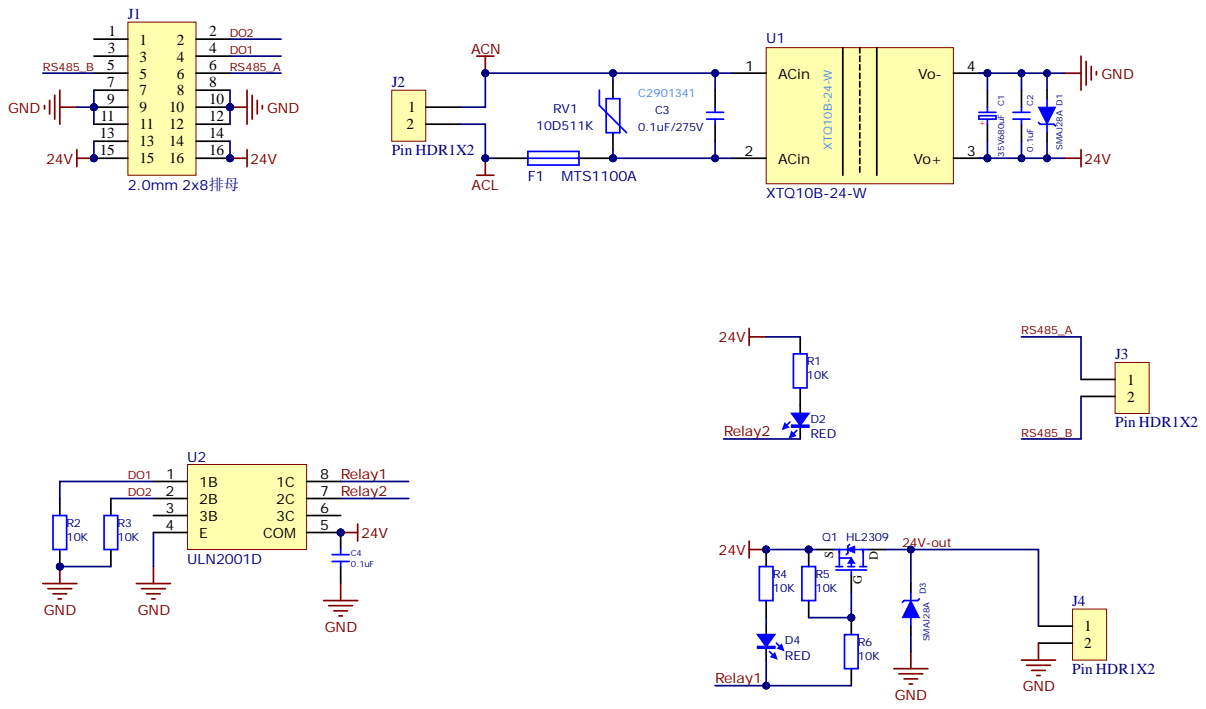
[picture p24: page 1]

DO2 | 2B 2
3B 3

Size A4 | Ver. 7 | Author Ling
Sheet 1 / 1 | | Data 20260416

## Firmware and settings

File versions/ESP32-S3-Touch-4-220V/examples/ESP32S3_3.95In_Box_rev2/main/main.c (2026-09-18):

/*
 * SPDX-FileCopyrightText: 2023-2024 Espressif Systems (Shanghai) CO LTD
 *
 * SPDX-License-Identifier: CC0-1.0
 * Modifications Copyright 2026 OSPTEK
 * https://github.com/osptek
*/

#include "esp_log.h"
#include "esp_heap_caps.h"
#include "driver/gpio.h"
#include "driver/i2c_master.h"
#include "driver/spi_master.h"
#include "freertos/FreeRTOS.h"
#include "freertos/task.h"
#include "esp_lcd_panel_ops.h"
#include "esp_lcd_panel_io.h"
#include "esp_lcd_panel_io_additions.h"
#include "esp_lcd_touch_ft5x06.h"
#include "esp_lcd_st7701.h"
#include "st7701_init_cmds.h"
#include "lv_demos.h"
#include "lvgl_port.h"

////////////////////////////////////////////////////////////////////////////////////////////////////////////////////////
//////////////////// Please update the following configuration according to your LCD spec //////////////////////////////
////////////////////////////////////////////////////////////////////////////////////////////////////////////////////////
#define EXAMPLE_LCD_H_RES (480)
#define EXAMPLE_LCD_V_RES (480)
#define EXAMPLE_LCD_BIT_PER_PIXEL (18)
#define EXAMPLE_RGB_BIT_PER_PIXEL (16)
#define EXAMPLE_RGB_DATA_WIDTH (16)
#define EXAMPLE_RGB_BOUNCE_BUFFER_SIZE (EXAMPLE_LCD_H_RES * CONFIG_EXAMPLE_LCD_RGB_BOUNCE_BUFFER_HEIGHT)
#define EXAMPLE_LCD_IO_SPI_CS (GPIO_NUM_45)
#define EXAMPLE_LCD_IO_SPI_SCL (GPIO_NUM_38)
#define EXAMPLE_LCD_IO_SPI_SDA (GPIO_NUM_39)

#define EXAMPLE_LCD_IO_RGB_DISP (-1) // -1 if not used
#define EXAMPLE_LCD_IO_RGB_VSYNC (GPIO_NUM_21)
#define EXAMPLE_LCD_IO_RGB_HSYNC (GPIO_NUM_14)
#define EXAMPLE_LCD_IO_RGB_DE (GPIO_NUM_47)
#define EXAMPLE_LCD_IO_RGB_PCLK (GPIO_NUM_48)

#define EXAMPLE_LCD_IO_RGB_DATA0 (GPIO_NUM_0)
#define EXAMPLE_LCD_IO_RGB_DATA1 (GPIO_NUM_12)
#define EXAMPLE_LCD_IO_RGB_DATA2 (GPIO_NUM_11)
#define EXAMPLE_LCD_IO_RGB_DATA3 (GPIO_NUM_10)
#define EXAMPLE_LCD_IO_RGB_DATA4 (GPIO_NUM_9)
#define EXAMPLE_LCD_IO_RGB_DATA5 (GPIO_NUM_46)
#define EXAMPLE_LCD_IO_RGB_DATA6 (GPIO_NUM_3)
#define EXAMPLE_LCD_IO_RGB_DATA7 (GPIO_NUM_20)
#define EXAMPLE_LCD_IO_RGB_DATA8 (GPIO_NUM_19)
#define EXAMPLE_LCD_IO_RGB_DATA9 (GPIO_NUM_8)
#define EXAMPLE_LCD_IO_RGB_DATA10 (GPIO_NUM_18)
#define EXAMPLE_LCD_IO_RGB_DATA11 (GPIO_NUM_17)
#define EXAMPLE_LCD_IO_RGB_DATA12 (GPIO_NUM_16)
#define EXAMPLE_LCD_IO_RGB_DATA13 (GPIO_NUM_15)
#define EXAMPLE_LCD_IO_RGB_DATA14 (GPIO_NUM_7)
#define EXAMPLE_LCD_IO_RGB_DATA15 (GPIO_NUM_6)

#define EXAMPLE_LCD_IO_RST (-1)                // -1 if not used
#define EXAMPLE_PIN_NUM_BK_LIGHT (GPIO_NUM_13) // -1 if not used
#define EXAMPLE_LCD_BK_LIGHT_ON_LEVEL (1)
#define EXAMPLE_LCD_BK_LIGHT_OFF_LEVEL !EXAMPLE_LCD_BK_LIGHT_ON_LEVEL

// #if EXAMPLE_LCD_TOUCH_CONTROLLER_FT5x06

#define EXAMPLE_TOUCH_I2C_SCL (GPIO_NUM_4)
#define EXAMPLE_TOUCH_I2C_SDA (GPIO_NUM_5)
#define EXAMPLE_TOUCH_RST     (GPIO_NUM_NC)
#define EXAMPLE_TOUCH_INT     (GPIO_NUM_NC)

/* Touch settings */
#define EXAMPLE_TOUCH_I2C_NUM       (I2C_NUM_0)
#define EXAMPLE_TOUCH_I2C_CLK_HZ    (400 * 1000)

// #endif


static const char *TAG = "example";

IRAM_ATTR static bool rgb_lcd_on_vsync_event(esp_lcd_panel_handle_t panel, const esp_lcd_rgb_panel_event_data_t *edata, void *user_ctx)
{
    return lvgl_port_notify_rgb_vsync();
}

void app_main()
{
    if (EXAMPLE_PIN_NUM_BK_LIGHT >= 0)
    {
        ESP_LOGI(TAG, "Turn off LCD backlight");
        gpio_config_t bk_gpio_config = {
            .mode = GPIO_MODE_OUTPUT,
            .pin_bit_mask = 1ULL << EXAMPLE_PIN_NUM_BK_LIGHT};
        ESP_ERROR_CHECK(gpio_config(&bk_gpio_config));
    }

    ESP_LOGI(TAG, "Install 3-wire SPI panel IO");
    spi_line_config_t line_config = {
        .cs_io_type = IO_TYPE_GPIO,
        .cs_gpio_num = EXAMPLE_LCD_IO_SPI_CS,
        .scl_io_type = IO_TYPE_GPIO,
        .scl_gpio_num = EXAMPLE_LCD_IO_SPI_SCL,
        .sda_io_type = IO_TYPE_GPIO,
        .sda_gpio_num = EXAMPLE_LCD_IO_SPI_SDA,
        .io_expander = NULL,
    };
    esp_lcd_panel_io_3wire_spi_config_t io_config = ST7701_PANEL_IO_3WIRE_SPI_CONFIG(line_config, 0);
    esp_lcd_panel_io_handle_t io_handle = NULL;
    ESP_ERROR_CHECK(esp_lcd_new_panel_io_3wire_spi(&io_config, &io_handle));

    ESP_LOGI(TAG, "Install ST7701 panel driver");
    esp_lcd_panel_handle_t lcd_handle = NULL;
    esp_lcd_rgb_panel_config_t rgb_config = {
        .clk_src = LCD_CLK_SRC_DEFAULT,
        .psram_trans_align = 64,
        .data_width = EXAMPLE_RGB_DATA_WIDTH,
        .bits_per_pixel = EXAMPLE_RGB_BIT_PER_PIXEL,
        .de_gpio_num = EXAMPLE_LCD_IO_RGB_DE,
        .pclk_gpio_num = EXAMPLE_LCD_IO_RGB_PCLK,
        .vsync_gpio_num = EXAMPLE_LCD_IO_RGB_VSYNC,
        .hsync_gpio_num = EXAMPLE_LCD_IO_RGB_HSYNC,
        .disp_gpio_num = EXAMPLE_LCD_IO_RGB_DISP,
        .data_gpio_nums = {
            EXAMPLE_LCD_IO_RGB_DATA0,
            EXAMPLE_LCD_IO_RGB_DATA1,
            EXAMPLE_LCD_IO_RGB_DATA2,
            EXAMPLE_LCD_IO_RGB_DATA3,
            EXAMPLE_LCD_IO_RGB_DATA4,
            EXAMPLE_LCD_IO_RGB_DATA5,
            EXAMPLE_LCD_IO_RGB_DATA6,
            EXAMPLE_LCD_IO_RGB_DATA7,
            EXAMPLE_LCD_IO_RGB_DATA8,
            EXAMPLE_LCD_IO_RGB_DATA9,
            EXAMPLE_LCD_IO_RGB_DATA10,
            EXAMPLE_LCD_IO_RGB_DATA11,
            EXAMPLE_LCD_IO_RGB_DATA12,
            EXAMPLE_LCD_IO_RGB_DATA13,
            EXAMPLE_LCD_IO_RGB_DATA14,
            EXAMPLE_LCD_IO_RGB_DATA15,
        },
        .timings ={                                 \
        .pclk_hz = 21 * 1000 * 1000,                \
        .h_res = 480,                               \
        .v_res = 480,                               \
        .hsync_pulse_width = 10,                    \
        .hsync_back_porch = 10,                     \
        .hsync_front_porch = 20,                    \
        .vsync_pulse_width = 10,                    \
        .vsync_back_porch = 10,                     \
        .vsync_front_porch = 10,                    \
        .flags.pclk_active_neg = false,             \
        },
        .flags.fb_in_psram = true,
        .num_fbs = LVGL_PORT_LCD_RGB_BUFFER_NUMS,
        .bounce_buffer_size_px = EXAMPLE_RGB_BOUNCE_BUFFER_SIZE,
    };
    rgb_config.timings.h_res = EXAMPLE_LCD_H_RES;
    rgb_config.timings.v_res = EXAMPLE_LCD_V_RES;
    st7701_vendor_config_t vendor_config = {
        .rgb_config = &rgb_config,
        .init_cmds = lcd_init_cmds, 
        .init_cmds_size = lcd_init_cmds_size,
        .flags = {
            .auto_del_panel_io = 0, /**
                                     * Set to 1 if panel IO is no longer needed after LCD initialization.
                                     * If the panel IO pins are sharing other pins of the RGB interface to save GPIOs,
                            #include "driver/i2c_master.h"         * Please set it to 1 to release the pins.
                                     */
            .mirror_by_cmd = 1,     // Set to 0 if `auto_del_panel_io` is enabled
        },
    };
    const esp_lcd_panel_dev_config_t panel_config = {
        .reset_gpio_num = EXAMPLE_LCD_IO_RST,
        .rgb_ele_order = LCD_RGB_ELEMENT_ORDER_RGB,
        .bits_per_pixel = EXAMPLE_LCD_BIT_PER_PIXEL,
        .vendor_config = &vendor_config,
    };
    ESP_ERROR_CHECK(esp_lcd_new_panel_st7701(io_handle, &panel_config, &lcd_handle));
    ESP_ERROR_CHECK(esp_lcd_panel_reset(lcd_handle));
    ESP_ERROR_CHECK(esp_lcd_panel_init(lcd_handle));
    esp_lcd_panel_disp_on_off(lcd_handle, true);

    esp_lcd_touch_handle_t tp_handle = NULL;
// #if EXAMPLE_LCD_TOUCH_CONTROLLER_FT5x06
    i2c_master_bus_handle_t i2c_handle = NULL;
    const i2c_master_bus_config_t i2c_config = {
        .i2c_port = EXAMPLE_TOUCH_I2C_NUM,
        .sda_io_num = EXAMPLE_TOUCH_I2C_SDA,
        .scl_io_num = EXAMPLE_TOUCH_I2C_SCL,
        .clk_source = I2C_CLK_SRC_DEFAULT,
        // .glitch_ignore_cnt = 7,
        .flags.enable_internal_pullup = true,
    };
    ESP_ERROR_CHECK(i2c_new_master_bus(&i2c_config, &i2c_handle));

    esp_lcd_panel_io_handle_t tp_io_handle = NULL;
    esp_lcd_panel_io_i2c_config_t tp_io_config = ESP_LCD_TOUCH_IO_I2C_FT5x06_CONFIG();
    tp_io_config.scl_speed_hz = EXAMPLE_TOUCH_I2C_CLK_HZ;
    ESP_ERROR_CHECK(esp_lcd_new_panel_io_i2c(i2c_handle, &tp_io_config, &tp_io_handle));

    ESP_LOGI(TAG, "Initialize touch controller FT5x06");
    const esp_lcd_touch_config_t tp_cfg = {
        .x_max = EXAMPLE_LCD_H_RES,
        .y_max = EXAMPLE_LCD_V_RES,
        .rst_gpio_num = EXAMPLE_TOUCH_RST,
        .int_gpio_num = EXAMPLE_TOUCH_INT,
        .levels = {
            .reset = 0,
            .interrupt = 0,
        },
        .flags = {
            .swap_xy = 0,
            .mirror_x = 0,
            .mirror_y = 0,
        },
    };
    ESP_ERROR_CHECK(esp_lcd_touch_new_i2c_ft5x06(tp_io_handle, &tp_cfg, &tp_handle));
// #endif

    ESP_ERROR_CHECK(lvgl_port_init(lcd_handle, tp_handle));

    esp_lcd_rgb_panel_event_callbacks_t cbs = {
#if EXAMPLE_RGB_BOUNCE_BUFFER_SIZE > 0
        .on_bounce_frame_finish = rgb_lcd_on_vsync_event,
#else
        .on_vsync = rgb_lcd_on_vsync_event,
#endif
    };
    esp_lcd_rgb_panel_register_event_callbacks(lcd_handle, &cbs, NULL);

    if (EXAMPLE_PIN_NUM_BK_LIGHT >= 0)
    {
        ESP_LOGI(TAG, "Turn on LCD backlight");
        gpio_set_level(EXAMPLE_PIN_NUM_BK_LIGHT, EXAMPLE_LCD_BK_LIGHT_ON_LEVEL);
    }

    ESP_LOGI(TAG, "Display LVGL demos");
    // Lock the mutex due to the LVGL APIs are not thread-safe
    if (lvgl_port_lock(-1))
    {
        // lv_demo_music();
        lv_demo_widgets();

        lv_obj_t *scr = lv_scr_act();
        ESP_LOGI(TAG, "scr: %p", scr);

        // Release the mutex
        lvgl_port_unlock();
    }
}

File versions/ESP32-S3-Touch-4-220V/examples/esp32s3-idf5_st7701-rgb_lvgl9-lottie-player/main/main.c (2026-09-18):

/*
 * SPDX-FileCopyrightText: Copyright 2026 OSPTEK
 * SPDX-License-Identifier: CC-BY-4.0
 *
 * https://github.com/osptek
 */

/**
 * @file main.c
 * @brief Unified LVGL demo supporting multiple LCD interface types
 *
 * This example demonstrates how to use LVGL with different LCD interfaces
 * (MIPI DSI, QSPI, RGB, SPI) in a single unified codebase.
 * The interface type and hardware configuration can be selected via menuconfig.
 *
 * For SPI/QSPI interfaces, the example automatically detects and uses GPIO TE
 * (Tearing Effect) synchronization if the panel provides a TE signal.
 */

#include "freertos/FreeRTOS.h"
#include "freertos/task.h"
#include "esp_log.h"
#include "esp_err.h"
#include "esp_check.h"
#include "driver/gpio.h"
#include <string.h>
#include <strings.h>
#include "sdkconfig.h"
#include "hw_init.h"
#include "esp_lv_adapter.h"
#include "esp_lv_lottie.h"
#include "esp_mmap_assets.h"
#include "mmap_generate_lottie.h"

static const char *TAG = "main";

/* FPS 监视器任务配置 */
#define FPS_MONITOR_TASK_STACK_SIZE    4096
#define FPS_MONITOR_TASK_PRIORITY      3
#define FPS_MONITOR_INTERVAL_MS        1000
#define LOTTIE_FS_ROOT                 "A:"
#define LOTTIE_PATH_MAX                128

static mmap_assets_handle_t s_lottie_assets;
static esp_lv_fs_handle_t s_fs_handle;

static bool lottie_is_json(const char *name)
{
    size_t len = strlen(name);
    if (len < 5) {
        return false;
    }
    return strcasecmp(name + len - 5, ".json") == 0;
}

static bool lottie_find_first_json(char *path, size_t path_size)
{
    int file_count = mmap_assets_get_stored_files(s_lottie_assets);
    for (int i = 0; i < file_count; i++) {
        const char *name = mmap_assets_get_name(s_lottie_assets, i);
        if (name == NULL || !lottie_is_json(name)) {
            continue;
        }
        int written = snprintf(path, path_size, "%s%s", LOTTIE_FS_ROOT, name);
        if (written > 0 && written < (int)path_size) {
            return true;
        }
    }

    return false;
}

/**
 * @brief Get the configured display rotation from Kconfig
 *
 * @return esp_lv_adapter_rotation_t Rotation angle
 */
static esp_lv_adapter_rotation_t get_configured_rotation(void)
{
#if CONFIG_EXAMPLE_DISPLAY_ROTATION_0
    return ESP_LV_ADAPTER_ROTATE_0;
#elif CONFIG_EXAMPLE_DISPLAY_ROTATION_90
    return ESP_LV_ADAPTER_ROTATE_90;
#elif CONFIG_EXAMPLE_DISPLAY_ROTATION_180
    return ESP_LV_ADAPTER_ROTATE_180;
#elif CONFIG_EXAMPLE_DISPLAY_ROTATION_270
    return ESP_LV_ADAPTER_ROTATE_270;
#else
    return ESP_LV_ADAPTER_ROTATE_0;
#endif
}

#if CONFIG_ESP_LVGL_ADAPTER_ENABLE_FPS_STATS
/**
 * @brief Task to monitor and log FPS statistics
 *
 * @param arg Pointer to lv_display_t
 */
static void fps_monitor_task(void *arg)
{
    lv_display_t *disp = (lv_display_t *)arg;
    uint32_t fps;

    while (1) {
        if (esp_lv_adapter_get_fps(disp, &fps) == ESP_OK) {
            ESP_LOGI(TAG, "Current FPS: %lu", fps);
        }
        vTaskDelay(pdMS_TO_TICKS(FPS_MONITOR_INTERVAL_MS));
    }
}
#endif

static esp_err_t lottie_mount_assets(void)
{
    const mmap_assets_config_t cfg = {
        .partition_label = "lottie",
        .max_files = MMAP_LOTTIE_FILES,
        .checksum = MMAP_LOTTIE_CHECKSUM,
        .flags = {
            .mmap_enable = true,
        },
    };

    ESP_RETURN_ON_ERROR(mmap_assets_new(&cfg, &s_lottie_assets), TAG, "mmap assets init failed");

    const fs_cfg_t fs_cfg = {
        .fs_letter = 'A',
        .fs_nums = MMAP_LOTTIE_FILES,
        .fs_assets = s_lottie_assets,
    };

    ESP_RETURN_ON_ERROR(esp_lv_adapter_fs_mount(&fs_cfg, &s_fs_handle), TAG, "fs mount failed");
    return ESP_OK;
}

static void lottie_demo_start(lv_display_t *disp)
{
    int32_t hor_res = lv_display_get_horizontal_resolution(disp);
    int32_t ver_res = lv_display_get_vertical_resolution(disp);
    int32_t size = (hor_res < ver_res) ? hor_res : ver_res;

    lv_obj_t *screen = lv_display_get_screen_active(disp);
    lv_obj_t *lottie = lv_lottie_create(screen);
    //lv_lottie_set_size(lottie, size, size);
    lv_lottie_set_size(lottie, 200, 300);
    lv_obj_center(lottie);

    char lottie_path[LOTTIE_PATH_MAX];
    if (!lottie_find_first_json(lottie_path, sizeof(lottie_path))) {
        ESP_LOGE(TAG, "No lottie assets found");
        return;
    }

    lv_lottie_set_src(lottie, lottie_path);
    if (!lv_lottie_is_loaded(lottie)) {
        ESP_LOGE(TAG, "Failed to load lottie asset: %s", lottie_path);
        return;
    }

    lv_lottie_set_loop_enabled(lottie, true);//设置循环播放
    lv_lottie_play(lottie);
}

void app_main()
{
    esp_lcd_panel_handle_t display_panel = NULL;
    esp_lcd_panel_io_handle_t display_io_handle = NULL;
    esp_lv_adapter_rotation_t rotation = get_configured_rotation();
    esp_lv_adapter_tear_avoid_mode_t tear_avoid_mode;
    esp_lv_adapter_display_config_t display_config;

    /* Select tear effect mode based on LCD interface type and TE availability */
#if CONFIG_EXAMPLE_LCD_INTERFACE_MIPI_DSI
    tear_avoid_mode = ESP_LV_ADAPTER_TEAR_AVOID_MODE_DEFAULT_MIPI_DSI;
    ESP_LOGI(TAG, "Selected LCD interface: MIPI DSI");
#elif CONFIG_EXAMPLE_LCD_INTERFACE_RGB
    tear_avoid_mode = ESP_LV_ADAPTER_TEAR_AVOID_MODE_DEFAULT_RGB;
    ESP_LOGI(TAG, "Selected LCD interface: RGB");
#else
    /* Check if TE (Tearing Effect) GPIO is available for SPI/QSPI interfaces */
    int te_gpio = hw_lcd_get_te_gpio();
    bool te_supported = (te_gpio != GPIO_NUM_NC);

    /* For SPI/QSPI interfaces, use TE_SYNC if available, otherwise use default */
    if (te_supported) {
        tear_avoid_mode = ESP_LV_ADAPTER_TEAR_AVOID_MODE_TE_SYNC;
        ESP_LOGI(TAG, "TE sync enabled on GPIO %d", te_gpio);
    } else {
        tear_avoid_mode = ESP_LV_ADAPTER_TEAR_AVOID_MODE_DEFAULT;
        ESP_LOGD(TAG, "TE sync disabled or unsupported (gpio=%d)", te_gpio);
    }
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

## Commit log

2026-08-18 docs: migrate panel series to main navigation and versions folders
    Collapse the four SKU branches into versions/{model} under main, matching the display-module layout, and point product pages back to the family index.
    [partitions.csv]
2026-08-18 docs: drop leftover branch wording on 220V product pages
2026-08-18 docs: update ESP32-S3-Touch-4-Pro product promo image
    Replace the Pro SKU hero shot with the Modbus holding-registers UI photo.
2026-08-31 docs(panel): switch display module to YDP395BT003-V4
    - replace the wrong B003 datasheet with the BT003 pack
    - add CAD, ST7701S, FT6336U, and init sequence on all SKUs
    [YDP395BT003-V4.dwg]
2026-09-09 docs(panel): add shared 86 enclosure CAD for all SKUs
    - publish 2-layer and 4-layer DWG files at repo-root docs/
    - link bilingual nav and product pages
    [0302(1).dwg, 3.95-01 PCB.dwg, WSD4寸-2d-1116.dwg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]
2026-09-18 feat(examples): refresh Touch-LCD-4 IDF samples for i2c_master
    - drop legacy i2c bringup on LCD-4, Classic, and 220V
    - add IDF5/IDF6 ST7701 RGB demos to all four SKUs
    - update bilingual README example tables
    [partitions.csv]
2026-09-20 feat(examples): keep only Pro-specific demo on Touch-4-Pro
    - replace shared ST7701 samples with esp32-s3-touch-lcd-4-pro-demo
    - leave LCD-4, Classic, and 220V examples unchanged
    [partitions.csv]
2026-09-30 docs(readme): follow module rename to YDP395BT009-V1
    [YDP395BT009-V1.dwg]
